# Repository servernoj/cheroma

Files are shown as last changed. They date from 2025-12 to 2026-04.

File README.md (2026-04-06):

# CheRoMa -- Chess Robotic Manipulator

This project represents work files to build and program a 4-DOF robotic manipulator intended to move chess pieces on the board by following live game broadcasted from chess.com (and lichess.org in near future) platforms. The arm is built from budgetary parts (servos, electromagnet, brackets) readily available for purchase from Amazon and other retailers. It also has a number of custom made 3D printed parts with CAD designs included in this repo.

As of April'26 this is a "work in progress" with completion rate of roughly 70-80%. The biggest challenge so far is the lack of precision of budgetary servos that negatively affects positioning of the arm in 3D space (error ±10mm) , which in turn results in inability for the arm to move specific chess piece from/to target position. This problem is being addressed by introducing a Digitizer -- platform allowing to calibrate robot's model params in real time by forcing it to move to specific positions and automatically reading 3D coordinates of the arrival point and using this data to fit model coefficients. 

## Demos

- Cheroma arm moving chess pieces https://www.youtube.com/shorts/CEkricqCiFo
- Cheroma Digitizer prototype is used for arm calibration https://www.youtube.com/shorts/9hFcoPiPavI

# Install the service

## Install NVM + Node + PNPM

Follow steps from https://github.com/nvm-sh/nvm?tab=readme-ov-file#installing-and-updating to install NVM

Then install `Node 22` and `pnpm`
```sh
nvm install 22
nvm alias default 22
npm i -g npm
```

## Install GitHub actions runner

Follow steps in `https://github.com/<username>/<repo>/settings/actions/runners/new`

## Install systemd service

Create file `/etc/systemd/system/cheroma.service` with the following content

```` ini
[Unit]
Description=CheRoMa API Service
After=network.target

[Service]
Type=simple
User=<username>
WorkingDirectory=/home/<username>/cheroma/apps/api
ExecStart=/bin/bash -lc 'source $HOME/.nvm/nvm.sh && node --env-file .env src/index.js'
Restart=on-failure
RestartSec=5
Environment=NODE_ENV=production
TimeoutStopSec=30s
KillSignal=SIGTERM
SendSIGKILL=yes

[Install]
WantedBy=multi-user.target
````
**Note**: replace `<username>` with your actual username on RasPi

Initialize the unit
```` sh
sudo systemctl daemon-reload
sudo systemctl start cheroma.service
````

Use the following to monitor the logs at realtime
```` sh
journalctl -u cheroma -f
```` 

# Misc
```sh
i2cset -y 1 0x40 0x00 0x10 # sleep
i2cset -y 1 0x40 0xFE 0x79 # frequency 50Hz
i2cset -y 1 0x40 0x00 0x20 # wake up + set auto-inc
i2cset -y 1 0x40 0x01 0x0C # set output + configure PWM reload logic

i2cset -y 1 0x40 0x06 0x00 0x00 0x40 0x01 i # center
```

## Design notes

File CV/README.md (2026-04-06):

# Vision server (Python + OpenCV + Flask)

REST API for camera capture and board / motion processing. Intended to run on a Raspberry Pi in production; development can use a Mac or Linux machine with a USB webcam.

## Requirements

- Python 3.10+ recommended (3.14+ tested)
- USB camera (or compatible capture device) when exercising the pipeline

## Setup on a new machine

From the repository root:

```bash
cd CV
python3 -m venv .venv
```

Activate the virtual environment:

- **macOS / Linux:** `source .venv/bin/activate`
- **Windows (cmd):** `.venv\Scripts\activate.bat`
- **Windows (PowerShell):** `.venv\Scripts\Activate.ps1`

Install dependencies:

```bash
pip install --upgrade pip
pip install -r requirements.txt
```

## Run the server

With the venv activated:

```bash
python app.py
```

By default the app listens on **127.0.0.1** port **5050**. Override with environment variables:

| Variable | Default | Description |
|---|---|---|
| `VISION_HOST`  | `127.0.0.1` | Bind address |
| `VISION_PORT`  | `5050` | Port |
| `FLASK_DEBUG`  | `1` | Set to `0` to disable Flask debug mode |
| `VISION_CAMERA_INDEX` | `0` | OpenCV camera index (see Webcam section) |
| `VISION_BOARD_DEBUG_DIR` | *(empty)* | If set: `find_board_corners` writes `overlay.png` there; overlay fit also writes per-candidate GIFs plus `overlay_fit_*_API_WINNER.gif`. Requires `imageio`. |
| `VISION_BOARD_CALIBRATION_FILE` | `CV/board_calibration.json` | Single global board quad (full-frame corners + frame size). |

Example:

```bash
VISION_HOST=0.0.0.0 VISION_PORT=5050 FLASK_DEBUG=0 python app.py
```

## Webcam on macOS (and Linux)

OpenCV does not use a device path like `/dev/video0` in your code on macOS. It opens cameras by **integer index**. Order is **not fixed** (built-in vs USB can swap). The backend on macOS is typically **AVFoundation**.

**macOS:** After unplugging a USB camera, the built-in camera may stay at **index 1** while **index 0** is empty. Probing **index 0** can then take **several seconds** before failing.

Use a working index when running your app or scripts:

```bash
export VISION_CAMERA_INDEX=1
```

**macOS privacy:** The process that runs Python needs camera permission (Terminal, iTerm2, **Cursor**, or **VS Code** if you run from the integrated terminal). Open **System Settings → Privacy & Security → Camera** and enable the app you use. If OpenCV prints “camera access has been denied,” grant access or run from a terminal app that is allowed.

**Programmatic access** in code:

```python
from vision import WebcamCapture

with WebcamCapture() as cam:  # uses VISION_CAMERA_INDEX, default 0
    ok, frame = cam.read()
```

## Check health

```bash
curl -s http://127.0.0.1:5050/health
```

Expected JSON: `{"status":"ok"}`

## Camera HTTP API (dev / test)

- **`GET /api/cameras`** — Runs `probe_cameras()`: one OpenCV index per device from `enumerate_cameras()`, keeping index and name aligned. JSON **`cameras`**: those that open and return a frame. If devices change while the process is running, restart the app so enumeration refreshes.

- **`GET /api/cameras/<index>`** — One **JPEG** frame from that index. Query: **`warmup`** (default `0`), **`quality`** (default `85`). Reopens the camera each request.

- **`GET /api/cameras/<index>/board`** — Warped **JPEG** using **saved calibration** only (no live edge detection). Query: **`warmup`**, **`quality`**, **`size`**. Returns **422** if calibration is missing or frame size does not match (recalibrate after resolution change).

- **`GET /api/cameras/<index>/board/overlay`** — Same warp and calibration gates as **`/board`**, then **first-pass** fit: symmetric scale from full-frame `cell = size/8` down to **`min_scale`×(size/8)`**. The winning scale maximizes **Pearson correlation** between **64 per-cell mean luminances** and a ±1 checker. **`n_steps`** (default **48**, clamped 8–256) is how many **`cell`** samples are placed on that range (inclusive endpoints). Headers **`X-Board-Overlay-Grid-Steps`**, **`X-Board-Overlay-Evaluated-Steps`**, **`X-Board-Overlay-Cell-Range`** report configured vs actually scored steps and `cell` endpoints. Default **`min_scale=0.75`** sweeps a **25%** shrink in `cell`; for a ~**5%** rim try **`min_scale`** closer to **1** (e.g. **`0.95`**). Query **`force_step`** (1-based index into the sweep) draws that step’s grid instead of the best score (preview). Query **`min_ncc`** only sets **`X-Board-Overlay-Meets-Min-Ncc`**. Also: **`warmup`**, **`quality`**, **`size`**, **`overlay_alpha`**.

- **`GET /api/cameras/<index>/board/calibration`** — Same JSON as a successful **POST** and the on-disk file: `ok`, and when calibrated `frame_width`, `frame_height`, `corners` (4×2). Returns `{"ok": false}` when none or invalid file. No capture. Calibration is global; the path index is not persisted.

- **`POST /api/cameras/<index>/board/calibration`** — Capture one frame from that index, run edge detection, **replace** stored calibration with one quad. OpenCV index is only used to open the device; it is not persisted. Returns **422** if no quad found.

- **`DELETE /api/cameras/<index>/board/calibration`** — Clear saved calibration (same global state for any index).

- **`GET /api/cameras/<index>/board-aruco`** — Dev endpoint (ArUco path); returns a JPEG (see `board_aruco`).

Examples:

```bash
curl -s http://127.0.0.1:5050/api/cameras | python3 -m json.tool
curl -s -o /tmp/cam0.jpg "http://127.0.0.1:5050/api/cameras/0"
curl -s http://127.0.0.1:5050/api/cameras/0/board/calibration | python3 -m json.tool
curl -s -X POST "http://127.0.0.1:5050/api/cameras/0/board/calibration"
curl -s -o /tmp/board.jpg "http://127.0.0.1:5050/api/cameras/0/board?size=800"
curl -s -o /tmp/board_overlay.jpg "http://127.0.0.1:5050/api/cameras/0/board/overlay?size=800"
curl -s -o /tmp/board_overlay_s10.jpg "http://127.0.0.1:5050/api/cameras/0/board/overlay?size=800&force_step=10"
```

## API stubs (to be implemented)

- `POST /api/reset` — reseed baseline / flags before a game
- `POST /api/listening/start` — begin the window where moves are expected
- `POST /api/listening/stop` — end that window

The virtual environment directory `.venv/` is gitignored; create it on each machine using the steps above.

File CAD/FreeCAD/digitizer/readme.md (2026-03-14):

The original design (file `base.FCStd`) of the digitizer case has an error related to how the origin of the digitizer pad, i.e. point in the middle of square outlined by pins 45,46,47,48 of the J2_01 connector, will positioned relative to the bottom-left mounting hole. By design their XY coordinates should match, so the digitizer origin should be right above the hole.

But in the implemented part the origin will have offset of 3.74mm towards X- and Y+. In this case when digitizer position will be defined as the `origin` param of the `[POST] /calibration` endpoint, the specified value (assumed to be aligned with the left-bottom mounting hole) will to to be adjusted correspondingly. 

For example, the user submitted `origin: [100, 150, 20]` the actual origin will be `[100 - 3.74, 150 + 3.74, 20]`

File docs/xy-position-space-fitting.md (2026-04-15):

# XY Position-Space Fitting — Design Context

## Hardware Overview

- **4-DOF robotic arm**: 1 yaw (base) + 3 pitch (shoulder, elbow, wrist)
- Hobby servos + 3D printed parts → imprecise positioning
- Wrist enforces tool-pitch constraint: `q3 = gamma - q1 - q2` (gamma=180°), keeping TCP vertical
- **TCP equipment**: electromagnet for grabbing chess pieces; stylus for digitizer calibration
- **Target application**: move chess pieces on a 320×320mm board (8×8, 40mm cells)

## Digitizer Platform

- 32×32 pin array, 160×160mm active area (= one quarter of the chess board)
- Touch registers (row, col) → converted to XY in robot frame via known origin offset
- Origin is measured in 3D arm coordinates; all touches share the same Z as the origin
- XY from digitizer is reliable; Z is NOT (3–15mm suspension travel before interrupt fires)
- Planned: 4 placements (board quarters) × 2 Z-levels = 8 sessions; currently only 1 origin is practical

## Why the Previous FK-Based Fitting Failed

### Approach
`Xmeas ≈ R(roll,pitch,yaw) · FK(a·Qcmd + b) + t` — fit per-servo scale/offset (a,b) + 6-DOF registration (R,t) using `lsqnonlin`.

### Problems identified

1. **XY-only residuals leave Z unconstrained** — registration angles (roll, pitch) and tz are weakly observable. The solver pushes them to bounds or trades them against servo params.

2. **Parameter ambiguity** — registration yaw vs base servo offset are confounded (both rotate XY). Translation tx,ty trade off with pitch-chain offsets. Different (R,t,a,b) combos produce identical XY predictions but wildly different Z behavior.

3. **Gamma constraint mismatch** — the fitter uses `q3 = gamma - q1_corrected - q2_corrected` (actual-side), but during calibration with identity correction the physical arm had `q3 = gamma - q1_commanded - q2_commanded + wrist_error`. The fitter's a,b absorb wrist error into shoulder/elbow corrections, making them non-physical. Switching to command-side gamma made a,b even less constrained (shoulder b jumped to −23°).

4. **Qcmd encodes a specific Z that the fitter ignores** — `Qcmd = IK(x_target, y_target, z_at_touch)` where z_at_touch varies per sample (interrupt timing). The fitter treats these angles as arbitrary, establishing no link between the commanded Z and the measured XY. Different Z → different Qcmd → same measured XY → the fitter cannot uniquely decompose the error.

## New Approach: Position-Space Fitting

Instead of decomposing error into per-joint corrections via FK, model the **XY positioning error as a function of target position** directly.

### Data model
For each calibration sample:
- **Target**: `(x_t, y_t)` — where we commanded the arm to go (known from grid geometry + origin)
- **Measured**: `(x_m, y_m)` — where the arm actually touched (from digitizer)
- **Error**: `(dx, dy) = (x_m - x_t, y_m - y_t)`

### Fitting
Model the error field:
```
dx(x, y) = a0 + a1·x + a2·y       (affine: 6 params)
dy(x, y) = b0 + b1·x + b2·y

dx(x, y) = a0 + a1·x + a2·y + a3·x² + a4·xy + a5·y²   (quadratic: 12 params)
dy(x, y) = b0 + b1·x + b2·y + b3·x² + b4·xy + b5·y²
```

Well-determined: 64 samples × 2 residuals vs 6–12 params. No FK, no registration, no ambiguity.

### Deployment
To reach desired `(x_d, y_d, z)`:
```
IK(x_d - dx(x_d, y_d),  y_d - dy(x_d, y_d),  z)
```
Pre-distort the target XY before feeding into IK. No servo correction layer needed.

### Z generalization
- Calibrate at two digitizer heights → two sets of affine/quadratic coefficients
- Interpolate coefficients for intermediate Z (chess piece heights range 35–75mm)

## Current State of the Codebase

**Branch**: `xy-position-space-fitting` (branched from `dev`)
**Restore tag**: `pre-xy-position-space-fitting` on `dev`

### What was removed
- `config.json`: top-level `fitting` (roll,pitch,yaw,t) + per-servo `fitting` (scale,offset)
- `@types/global.d.ts`: `Fitting` type, `ServoFitting` type, `fitting` fields on `ServoData` and `Config`
- `modules/kinematics.js`: `toModel()` function, `fitting` variable, `Matrix`/`rotationMatrix` imports; `IKK` simplified to `K2S(IK(P))`
- `modules/servo.js`: `angleDegToPulseUs` no longer applies scale/offset — angle goes straight to calPoints; `line()` uses `IKK` instead of `K2S(IK(toModel(...)))`
- `controller/config.js`: `fittingSchema`, `servoFittingSchema`, `fitting` from PATCH schema
- `modules/xyzFitting.js`: deleted (old JS Levenberg-Marquardt fitter)
- `fit-calibration.js`: deleted (CLI entry point for old fitter)
- `package.json`: removed `fit-calibration` script

### What remains unchanged
- `modules/calibration.js` — calibration experiment workflow (descent, touch, record)
- `controller/calibration.js` — POST endpoint returning CSV
- `modules/arm.js`, `controller/arm.js` — arm motion (use IKK, which now passes through directly)
- `matlab/xy_fitting.m` — Matlab XY fitter (kept for reference, not used going forward)
- `matlab/xyz_fitting.m` — Matlab XYZ fitter (kept for reference)

## TODO — Next Steps

1. **Update calibration CSV format**: include `x_target, y_target` (known from grid) alongside `x_measured, y_measured` (from digitizer). Qcmd columns may become optional or removed.

2. **Implement position-space fitter** (JS module): least-squares fit of affine or polynomial error model from (target, measured) pairs.

3. **Add XY correction to config**: new config section for the polynomial coefficients (replaces old fitting block).

4. **Integrate correction into IKK** (or a new wrapper): apply pre-distortion before IK.

5. **Collect fresh calibration data** with identity correction (current state) and validate the new approach.

6. **Multi-Z support**: repeat calibration at elevated digitizer, fit per-Z, implement interpolation.

## Key Files for Context

| File | Role |
|---|---|
| `apps/api/src/modules/kinematics.js` | FK, IK, IKK (now raw) |
| `apps/api/src/modules/servo.js` | Angle→pulse, motion planning, `line()` |
| `apps/api/src/modules/calibration.js` | Calibration experiment: grid traversal, descent, digitizer read |
| `apps/api/src/controller/calibration.js` | HTTP endpoint for calibration |
| `apps/api/src/modules/arm.js` | High-level arm motions (descent, lift, search) |
| `apps/api/src/config.json` | Runtime config (geom, servos, board) |
| `apps/api/src/@types/global.d.ts` | TypeScript type definitions |
| `apps/api/take_1.csv` | Sample calibration data (64 rows, 7 cols) |

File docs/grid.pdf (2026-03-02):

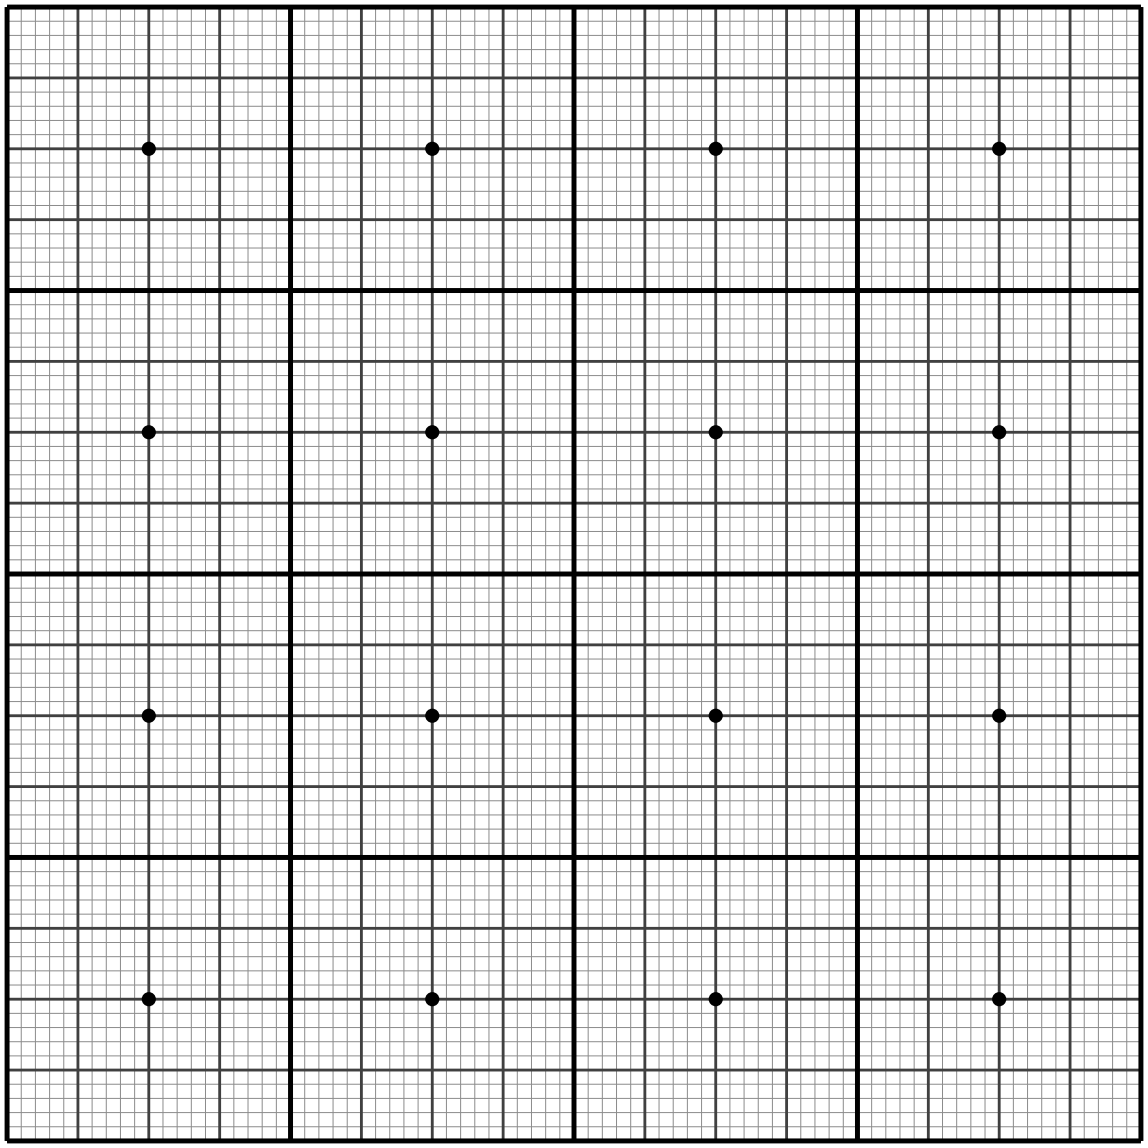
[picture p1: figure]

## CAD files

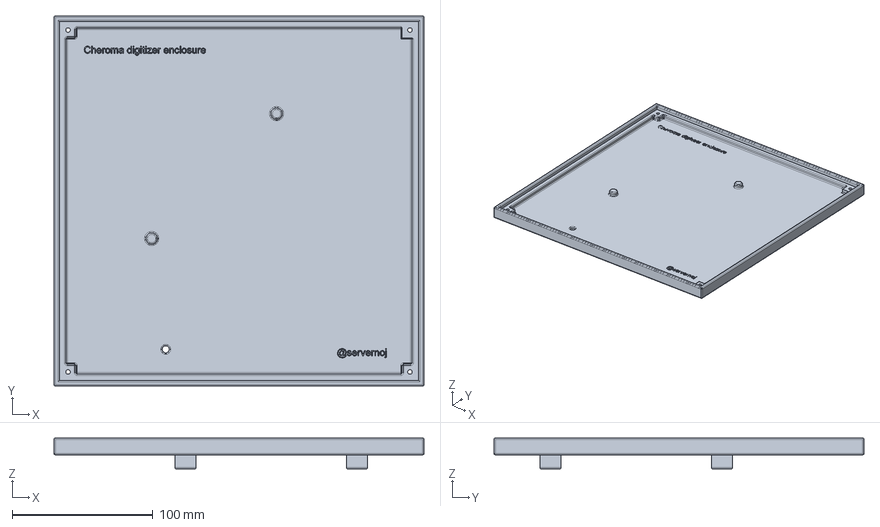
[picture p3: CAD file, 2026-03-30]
CAD/FreeCAD/digitizer/base_rev1.2.FCStd
263.0 x 263.0 x 22.0 mm

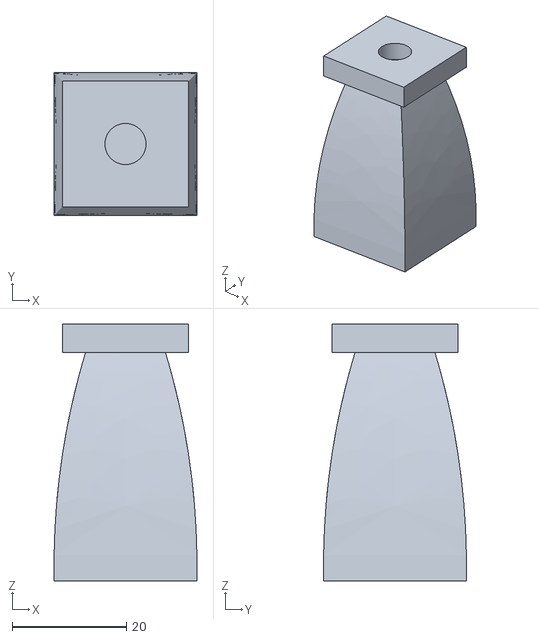
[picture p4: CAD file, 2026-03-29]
CAD/FreeCAD/pieces/hollow/pieces-rook.stl
25.0 x 25.0 x 45.0

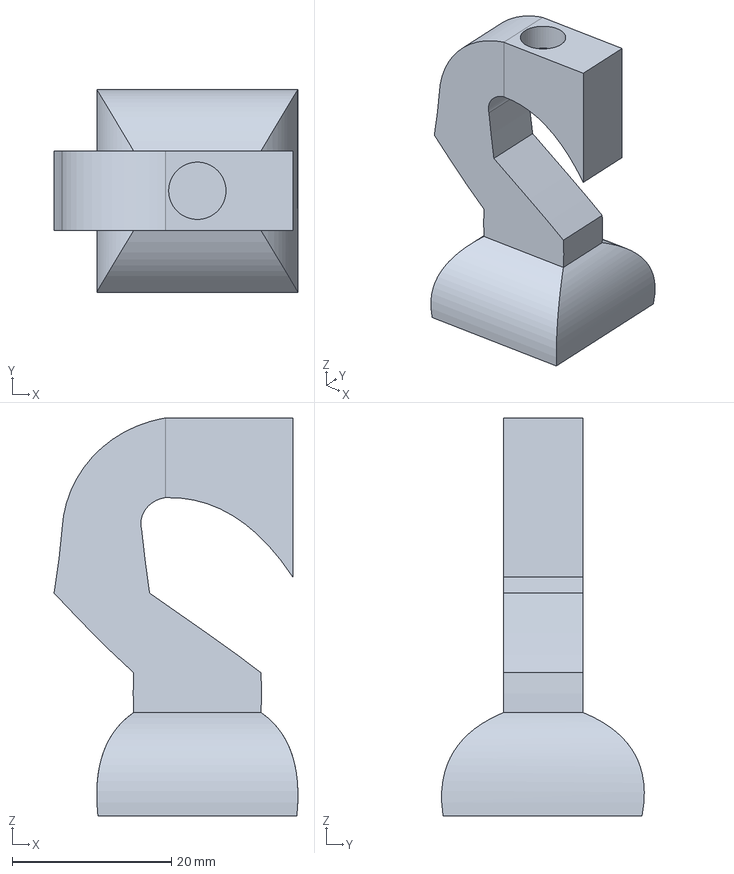
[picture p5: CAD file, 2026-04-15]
CAD/FreeCAD/pieces/pieces.FCStd
30.6 x 25.5 x 50.0 mm

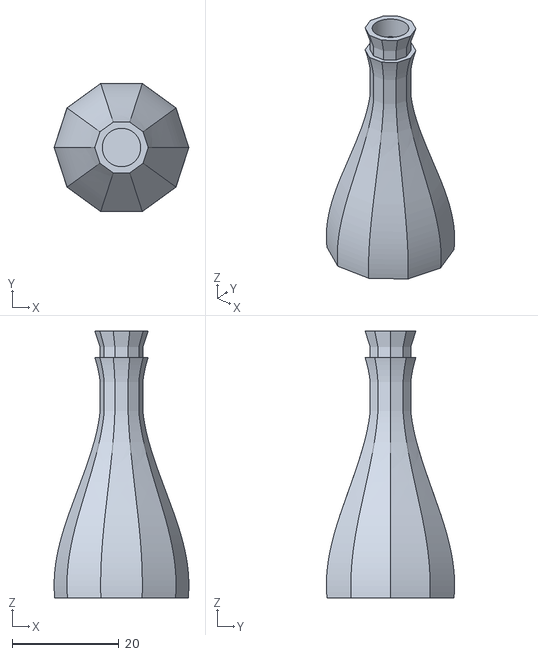
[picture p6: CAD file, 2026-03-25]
CAD/FreeCAD/pieces/solid/pieces-bishop.stl
25.2 x 24.0 x 50.0

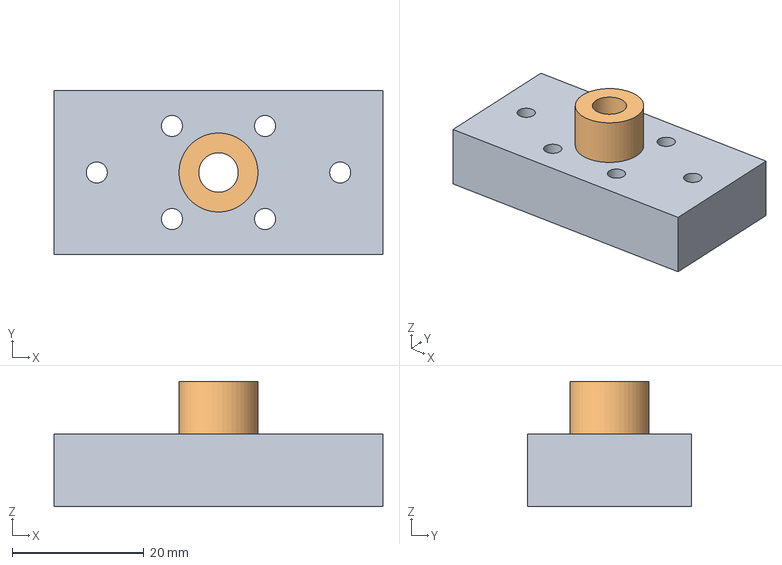
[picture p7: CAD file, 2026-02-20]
CAD/FreeCAD/TCP/tcp_adapter.FCStd
50.0 x 25.0 x 19.0 mm
holder
insert

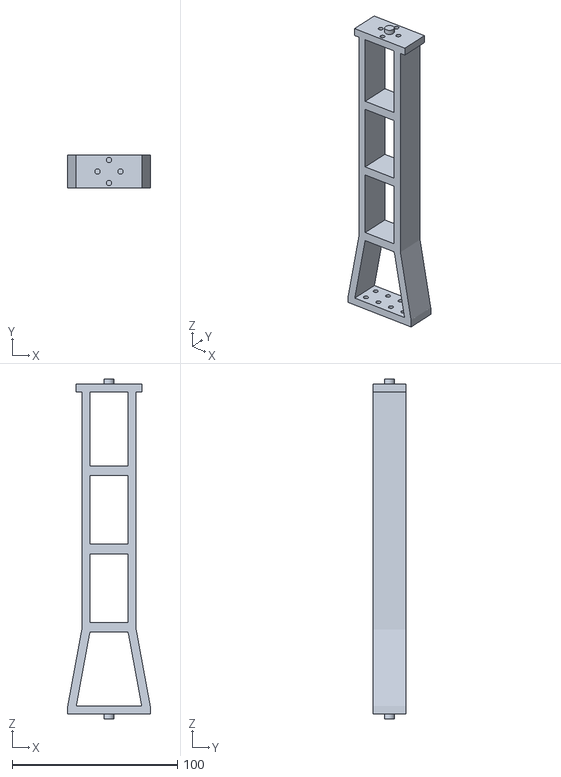
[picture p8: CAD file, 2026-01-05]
CAD/OpenSCAD/P2.stl
50.0 x 20.0 x 206.0

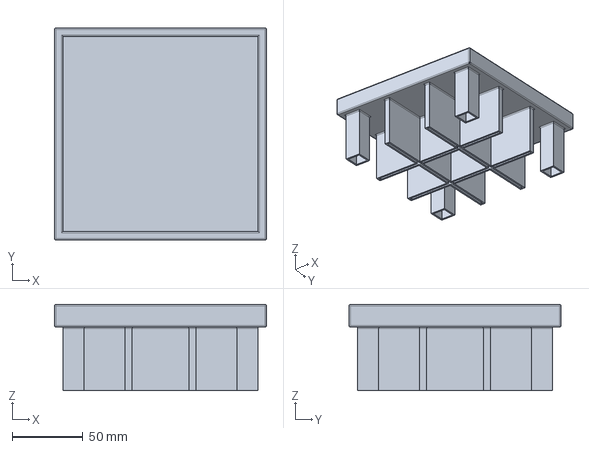
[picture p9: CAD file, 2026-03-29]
CAD/FreeCAD/digitizer/spacer_rev1.1.FCStd
150.0 x 150.0 x 61.0 mm

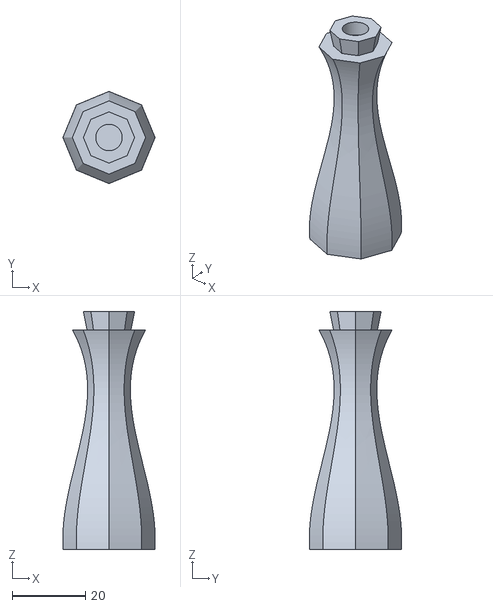
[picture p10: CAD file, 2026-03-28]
CAD/FreeCAD/pieces/hollow/pieces-queen.stl
25.2 x 25.2 x 65.0

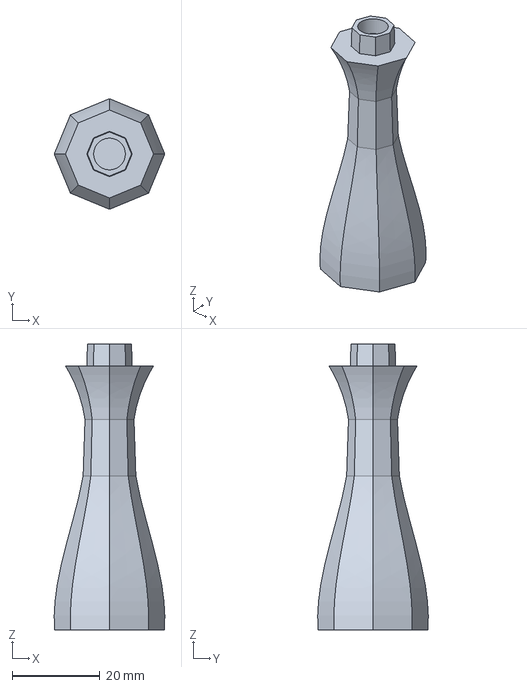
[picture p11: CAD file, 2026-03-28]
CAD/FreeCAD/pieces/pieces-solid.FCStd
25.1 x 25.1 x 65.0 mm

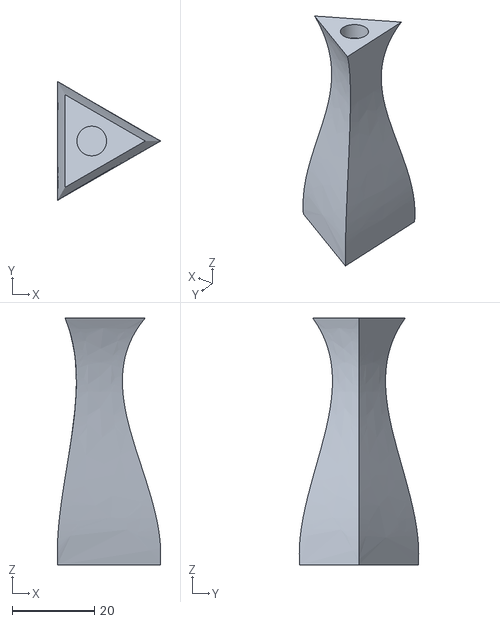
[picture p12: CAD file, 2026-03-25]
CAD/FreeCAD/pieces/solid/pieces-king.stl
25.1 x 29.0 x 60.0

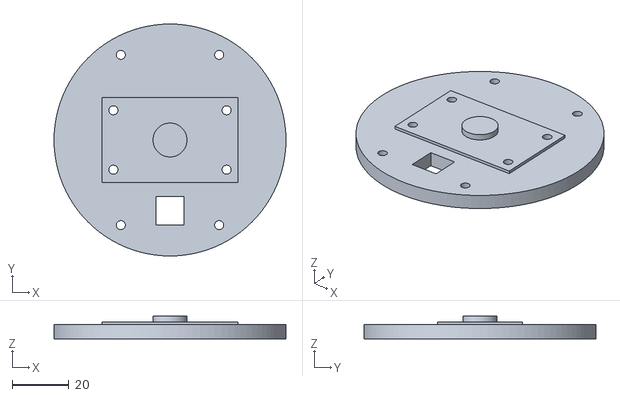
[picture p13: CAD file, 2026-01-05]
CAD/OpenSCAD/base_rds_5180.stl
82.0 x 82.0 x 8.00

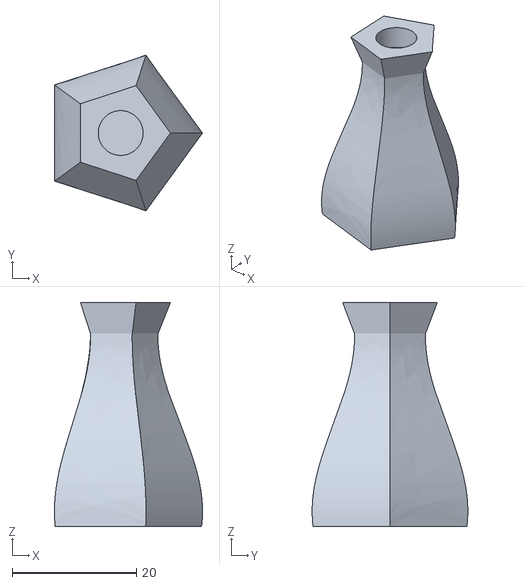
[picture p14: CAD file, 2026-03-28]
CAD/FreeCAD/pieces/hollow/pieces-pawn.stl
23.8 x 25.0 x 36.0

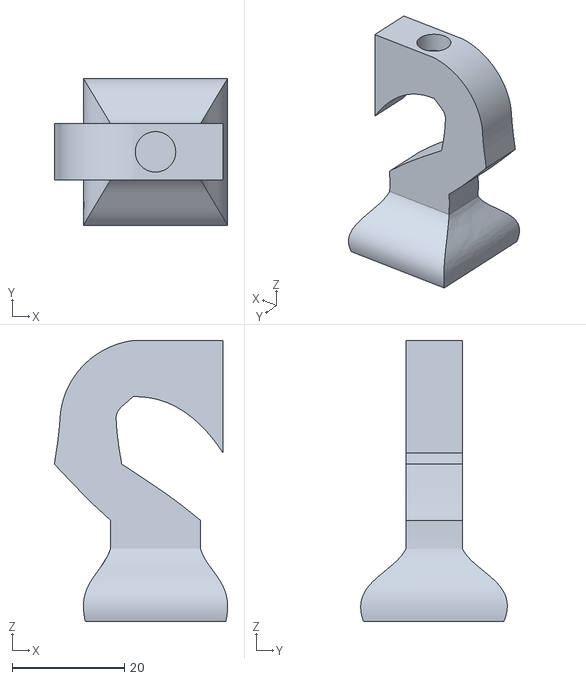
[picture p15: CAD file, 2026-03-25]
CAD/FreeCAD/pieces/solid/pieces-knight.stl
30.8 x 26.1 x 50.0

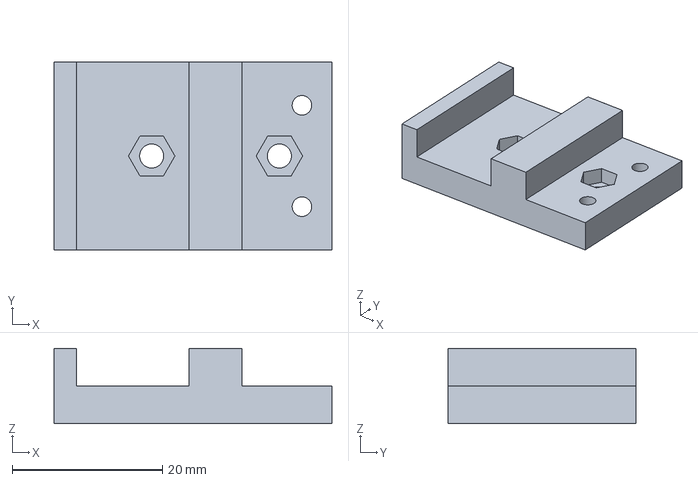
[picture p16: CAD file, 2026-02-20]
CAD/FreeCAD/TCP/pcb_holder.FCStd
37.0 x 25.0 x 10.0 mm

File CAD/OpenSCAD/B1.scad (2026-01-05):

// B1 bracket interface (visual approval model)
//
// Geometry described by user:
// - Outer interface rectangle: 56mm x 21mm
// - Center hole: Ø9mm at (0,0)
// - M3 holes:
//   - 8 holes at corners AND edge-centers of an inscribed aligned rectangle 42mm x 14mm
//     (i.e. corners ±21,±7 plus edge centers ±21,0 and 0,±7)
//   - 2 additional M3 holes on the long symmetry axis (X axis) at x=±7mm

// ----------------------------
// Parameters
// ----------------------------
plate_x = 56;            // mm (long dimension)
plate_y = 21;            // mm (short dimension)
plate_thickness = 3;     // mm (visualization thickness)

center_hole_d = 9;       // mm
m3_hole_d = 3.2;         // mm (clearance)

// Inscribed rectangle for the 8-hole pattern
inscribed_x = 42;        // mm (along X)
inscribed_y = 14;        // mm (along Y)

$fn = 96;

// ----------------------------
// Helpers
// ----------------------------
module hole(d, h) {
    cylinder(d=d, h=h, center=true);
}

module plate() {
    linear_extrude(height=plate_thickness)
        square([plate_x, plate_y], center=true);
}

module b1_holes() {
    h = plate_thickness + 2;

    // Center Ø9 hole
    translate([0, 0, plate_thickness/2])
        hole(center_hole_d, h);

    // 8 M3 holes: corners + edge-centers of inscribed rectangle
    ix = inscribed_x/2;
    iy = inscribed_y/2;

    // corners
    for (sx = [-1, 1], sy = [-1, 1])
        translate([sx*ix, sy*iy, plate_thickness/2])
            hole(m3_hole_d, h);

    // edge centers
    for (sx = [-1, 1])
        translate([sx*ix, 0, plate_thickness/2])
            hole(m3_hole_d, h);

    for (sy = [-1, 1])
        translate([0, sy*iy, plate_thickness/2])
            hole(m3_hole_d, h);

    // 2 additional M3 holes on long symmetry axis at x=±7
    for (sx = [-1, 1])
        translate([sx*7, 0, plate_thickness/2])
            hole(m3_hole_d, h);
}

// ----------------------------
// Model
// ----------------------------
difference() {
    plate();
    b1_holes();
}

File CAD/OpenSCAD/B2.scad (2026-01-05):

// B2 bracket interface (visual approval model)
//
// Geometry described by user:
// - Outer interface rectangle: 40mm x 20mm
// - Center hole: Ø6mm at (0,0)
// - 4x M3 holes on lines of symmetry, spaced 7mm from center:
//   (±7, 0) and (0, ±7)
//
// Coordinate system:
// - Origin at plate center
// - X = long axis (40mm)
// - Y = short axis (20mm)

// ----------------------------
// Parameters
// ----------------------------
plate_x = 40;            // mm
plate_y = 20;            // mm
plate_thickness = 3;     // mm (visualization thickness)

center_hole_d = 6;       // mm
m3_hole_d = 3.2;         // mm (clearance)

hole_offset = 7;         // mm from center along symmetry axes

$fn = 96;

module hole(d, h) {
    cylinder(d=d, h=h, center=true);
}

module plate() {
    linear_extrude(height=plate_thickness)
        square([plate_x, plate_y], center=true);
}

difference() {
    plate();

    h = plate_thickness + 2;

    // Center hole
    translate([0, 0, plate_thickness/2])
        hole(center_hole_d, h);

    // 4x M3 holes at (±7,0), (0,±7)
    for (sx = [-1, 1])
        translate([sx*hole_offset, 0, plate_thickness/2])
            hole(m3_hole_d, h);

    for (sy = [-1, 1])
        translate([0, sy*hole_offset, plate_thickness/2])
            hole(m3_hole_d, h);
}

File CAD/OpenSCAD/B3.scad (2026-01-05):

// B3 bracket interface (visual approval model)
//
// Geometry described by user:
// - Outer interface rectangle: 50mm x 20mm
// - Center hole: Ø6mm at (0,0)
// - 8x M3 holes located at the corners of THREE squares placed side-by-side
//   along the long symmetry axis (X axis), with the middle square centered at origin.
//
// Interpretation (yields 8 holes as stated):
// - The 3 squares share edges (forming a 1x3 strip), so their corner set is a 4x2 grid.
// - Each square has diagonal = 14mm, so side = 14/sqrt(2).
// - Hole coordinates are at x = (-1.5a, -0.5a, +0.5a, +1.5a) and y = (±a/2), where a=side.
//
// Coordinate system:
// - Origin at plate center
// - X = long axis (50mm)
// - Y = short axis (20mm)

// ----------------------------
// Parameters
// ----------------------------
plate_x = 50;            // mm
plate_y = 20;            // mm
plate_thickness = 3;     // mm (visualization thickness)

center_hole_d = 6;       // mm
m3_hole_d = 3.2;         // mm (clearance)

square_diag = 14;        // mm (diagonal of each square)

$fn = 96;

module hole(d, h) {
    cylinder(d=d, h=h, center=true);
}

module plate() {
    linear_extrude(height=plate_thickness)
        square([plate_x, plate_y], center=true);
}

// ----------------------------
// Model
// ----------------------------
difference() {
    plate();

    h = plate_thickness + 2;

    // Center hole
    translate([0, 0, plate_thickness/2])
        hole(center_hole_d, h);

    // 8x M3 holes from 3 edge-sharing squares
    a = square_diag / sqrt(2); // side length

    xs = [-1.5*a, -0.5*a, 0.5*a, 1.5*a];
    ys = [-0.5*a, 0.5*a];

    for (x = xs, y = ys)
        translate([x, y, plate_thickness/2])
            hole(m3_hole_d, h);
}

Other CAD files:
CAD/FreeCAD/TCP/tcp_assembly.FCStd
CAD/OpenSCAD/P1.stl
CAD/FreeCAD/pieces/hollow/pieces-bishop.stl
CAD/FreeCAD/pieces/solid/pieces-pawn.stl
CAD/OpenSCAD/base.scad
CAD/FreeCAD/TCP/pcb_holder.stl
CAD/FreeCAD/TCP/tcp_adapter.stl
CAD/FreeCAD/digitizer/base_rev1.2.stl
CAD/FreeCAD/digitizer/spacer.FCStd
CAD/FreeCAD/digitizer/spacer_rev1.1.stl
CAD/FreeCAD/pieces/hollow/pieces-king.stl
CAD/FreeCAD/pieces/hollow/pieces-knight.stl
CAD/FreeCAD/pieces/solid/pieces-queen.stl
CAD/FreeCAD/pieces/solid/pieces-rook.stl
CAD/OpenSCAD/P1.scad
CAD/OpenSCAD/P2.scad
CAD/OpenSCAD/P3.scad
CAD/OpenSCAD/P3.stl

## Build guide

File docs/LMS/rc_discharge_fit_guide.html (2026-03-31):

# RC discharge: identify \(V_0\) and \(\tau\) from \((t, V)\) data

Step-by-step guide for MATLAB. You enter ts and vs and run the steps yourself. Math below uses LaTeX (MathJax). No noise is assumed in your synthetic experiment.

## Model and residual

Time constant \(\tau = RC\). Ideal capacitor discharge:

$$V(t) = V_0\, e^{-t/\tau}$$

Parameter vector (column \(2 \times 1\)):

$$\mathbf{p} = \begin{pmatrix} V_0 \\ \tau \end{pmatrix}$$

For each sample \(k = 1,\ldots,N\), with measurements \((t_k, V^{\mathrm{meas}}_k)\) stored as ts(k), vs(k):

$$r_k(\mathbf{p}) = V^{\mathrm{meas}}_k - V_0\, e^{-t_k/\tau}$$

Stack \(\mathbf{r}(\mathbf{p}) = [r_1,\ldots,r_N]^\top\). Objective (half sum of squares):

$$\Phi(\mathbf{p}) = \tfrac{1}{2}\,\|\mathbf{r}\|_2^2 = \tfrac{1}{2}\sum_{k=1}^N r_k^2$$

## Stage 0 — Data in MATLAB and a plot

You do:

1. Define column vectors ts and vs.
2. plot(ts, vs, 'o'); label axes.
3. Check numel(ts) == numel(vs).

Why: If \(t=0\) is the start of discharge, \(V_0\) is the model value at \(t=0\) (possibly extrapolated if your first sample has \(t_1 > 0\)).

## Stage 1 — Residual function \(\mathbf{r}(\mathbf{p})\)

You do: Implement r = residual_rc(p, ts, vs) with p(1)=V_0, p(2)=tau:

function r = residual_rc(p, ts, vs)
  V0 = p(1);
  tau = p(2);
  vhat = V0 * exp(-ts / tau);
  r = vs - vhat;
end

Pick a trial \(\mathbf{p}_0 = [V_{0,\mathrm{guess}};\,\tau_{\mathrm{guess}}]^\top\). Compute r0 = residual_rc(p0, ts, vs) and

$$\Phi(\mathbf{p}_0) = \tfrac{1}{2}\,\mathbf{r}_0^\top \mathbf{r}_0$$

## Stage 2a — Numerical Jacobian \(\mathbf{J}\)

Dimensions: \(\mathbf{J} \in \mathbb{R}^{N \times 2}\), with \(J_{kj} = \partial r_k / \partial p_j\).

Meaning of \(\mathbf{e}_1\), \(\mathbf{e}_2\), \(h_1\), \(h_2\).

\(\mathbf{e}_1\) and \(\mathbf{e}_2\) are the standard basis vectors in \(\mathbb{R}^2\) (you have two parameters):

$$\mathbf{e}_1 = \begin{pmatrix} 1 \\ 0 \end{pmatrix}, \qquad \mathbf{e}_2 = \begin{pmatrix} 0 \\ 1 \end{pmatrix}$$

So \(\mathbf{p} + h_1 \mathbf{e}_1\) bumps only \(V_0\) by \(h_1\), and \(\mathbf{p} + h_2 \mathbf{e}_2\) bumps only \(\tau\) by \(h_2\). Each column of \(\mathbf{J}\) is the rate of change of \(\mathbf{r}\) along one coordinate of \(\mathbf{p}\).

\(h_1\) and \(h_2\) are small finite-difference step sizes for those two coordinates. They may differ because \(V_0\) and \(\tau\) can live on very different scales (e.g. volts vs seconds). A common rule is something like \(h_j \sim 10^{-6}\max(1, |p_j|)\), not necessarily one shared \(h\) for both.

In each case you approximate a partial derivative:

$$\frac{\partial \mathbf{r}}{\partial p_j} \approx \frac{\mathbf{r}(\mathbf{p} + h_j \mathbf{e}_j) - \mathbf{r}(\mathbf{p})}{h_j}$$

Forward differences (you choose small \(h_1, h_2\)):

$$\mathbf{J}_{:1} \approx \frac{\mathbf{r}(\mathbf{p} + h_1 \mathbf{e}_1) - \mathbf{r}(\mathbf{p})}{h_1}, \qquad \mathbf{J}_{:2} \approx \frac{\mathbf{r}(\mathbf{p} + h_2 \mathbf{e}_2) - \mathbf{r}(\mathbf{p})}{h_2}$$

with \(\mathbf{e}_1 = [1,0]^\top\), \(\mathbf{e}_2 = [0,1]^\top\). In MATLAB: e1 = [1;0]; e2 = [0;1]; then build J(:,1), J(:,2); confirm size(J) == [N,2].

## Stage 3 — Gauss–Newton step

Normal equations for the Gauss–Newton increment \(\Delta\mathbf{p}\):

$$\mathbf{J}^\top \mathbf{J}\,\Delta\mathbf{p} = -\mathbf{J}^\top \mathbf{r}$$

Then \(\mathbf{p}_{\mathrm{new}} = \mathbf{p} + \Delta\mathbf{p}\).

A = J' * J;
b = -(J' * r0);
dp = A \ b;
p1 = p0 + dp;

Recompute \(\mathbf{r}\) at \(\mathbf{p}_1\); compare \(\Phi\) before and after. Loop until \(\|\Delta\mathbf{p}\|\) is small.

## Stage 2b — Analytical Jacobian

Predicted voltage \(\hat{V}(t) = V_0 e^{-t/\tau}\). Since \(r_k = V^{\mathrm{meas}}_k - \hat{V}(t_k)\),

$$\frac{\partial r_k}{\partial V_0} = -\frac{\partial \hat{V}}{\partial V_0}, \qquad \frac{\partial r_k}{\partial \tau} = -\frac{\partial \hat{V}}{\partial \tau}$$

Derivatives of \(\hat{V}(t) = V_0 e^{-t/\tau}\):

$$\frac{\partial \hat{V}}{\partial V_0} = e^{-t/\tau}$$

Using \(\dfrac{d}{d\tau} e^{-t/\tau} = e^{-t/\tau}\cdot \dfrac{t}{\tau^2}\):

$$\frac{\partial \hat{V}}{\partial \tau} = V_0\, e^{-t/\tau}\,\frac{t}{\tau^2}$$

So (column-wise, evaluated at each ts(k)):

$$\mathbf{J}_{:1} = -\exp(-\mathbf{t}/\tau), \qquad \mathbf{J}_{:2} = -V_0\, \exp(-\mathbf{t}/\tau) \odot (\mathbf{t}/\tau^2)$$

where \(\mathbf{t}\) is the vector ts and \(\odot\) is element-wise product (use .* in MATLAB).

You do: J = jacobian_rc_analytic(p, ts) returning N×2; repeat Stage 3.

## Stage 4 — Optional: Levenberg–Marquardt

What is \(\Phi\)? The scalar objective you minimize is the half sum of squared residuals (same \(\Phi\) as in the model section):

$$\Phi(\mathbf{p}) = \tfrac{1}{2}\,\|\mathbf{r}(\mathbf{p})\|_2^2 = \tfrac{1}{2}\sum_k r_k^2.$$

So “\(\Phi\) decreased” means the total squared error decreased. Each GN/LM step tries to choose \(\Delta\mathbf{p}\) so that \(\Phi(\mathbf{p}+\Delta\mathbf{p})\) is smaller than \(\Phi(\mathbf{p})\), using a linear approximation of \(\mathbf{r}\) near \(\mathbf{p}\).

What is \(\lambda\)? A non‑negative damping parameter (Levenberg–Marquardt). It does not come from the RC physics; it is only a numerical knob for the solver. Roughly:

- \(\lambda\) small → the step is close to Gauss–Newton (uses \(\mathbf{J}^\top\mathbf{J}\) aggressively).
- \(\lambda\) large → the step is smaller and behaves more like a short move along the negative gradient of \(\Phi\) (since \(\mathbf{J}^\top\mathbf{r} = \nabla\Phi\)), i.e. more cautious.

In practice: increase \(\lambda\) when a proposed step would increase \(\Phi\) or is unstable; decrease \(\lambda\) when steps are accepted and convergence is healthy.

Why add \(\lambda \mathbf{I}\) to \(\mathbf{J}^\top\mathbf{J}\)? The Gauss–Newton system is \(\mathbf{J}^\top\mathbf{J}\,\Delta\mathbf{p} = -\mathbf{J}^\top\mathbf{r}\). Two common failures:

1. Singular or ill‑conditioned \(\mathbf{J}^\top\mathbf{J}\): the solve for \(\Delta\mathbf{p}\) is badly posed; \(\Delta\mathbf{p}\) can be huge or hypersensitive to tiny errors.
2. Linearization poor far from the minimum: a full GN step can overshoot, so \(\Phi(\mathbf{p}+\Delta\mathbf{p}) > \Phi(\mathbf{p})\).

Replacing \(\mathbf{J}^\top\mathbf{J}\) by \(\mathbf{J}^\top\mathbf{J} + \lambda \mathbf{I}\) gives:

$$(\mathbf{J}^\top \mathbf{J} + \lambda \mathbf{I})\,\Delta\mathbf{p} = -\mathbf{J}^\top \mathbf{r}$$

Effects: (i) With \(\lambda > 0\), the matrix is better conditioned (strictly positive definite in the usual case), so the linear system for \(\Delta\mathbf{p}\) is more stable and wild steps from near‑singularity are curbed. (ii) Increasing \(\lambda\) shrinks \(\Delta\mathbf{p}\), trading GN aggressiveness for robustness when the quadratic model of \(\Phi\) is unreliable.

One‑line intuition: GN trusts the linearization fully; LM adds “\(\lambda \mathbf{I}\)” to damp the step—if the full GN move is bad, blend in a shorter, gradient‑like correction.

You do: Implement the same solve with A = J'*J + lambda*eye(2), tune \(\lambda\) by hand, or mirror the accept/reject schedule used in your JS fitter.

## Stage 5 — MATLAB lsqnonlin (check)

lsqnonlin(@(p) residual_rc(p, ts, vs), p0, ...) and compare to your GN iterations.

## Stage 6 — Optional: log-domain line fit (warm start only)

If \(V_k > 0\) for all \(k\), then \(\ln V_k = \ln V_0 - t_k/\tau\) is affine in \(t_k\). Linear regression on \((t_k, \ln V_k)\) gives rough \((\ln V_0,\, -1/\tau)\) — useful for \(\mathbf{p}_0\), not a replacement for nonlinear least squares when noise or model mismatch matter.

## Appendix — Why \(\Phi\) decreases: gradient and descent direction

This section generalizes beyond the RC example. Read the formulas here with MathJax rendering enabled.

Objective and gradient. With \(\Phi(\mathbf{p}) = \tfrac{1}{2}\,\|\mathbf{r}(\mathbf{p})\|_2^2\), one has (chain rule):

$$\nabla \Phi(\mathbf{p}) = \mathbf{J}(\mathbf{p})^\top \mathbf{r}(\mathbf{p})$$

The gradient is a vector in \(\mathbb{R}^M\). It points in the direction of steepest increase of \(\Phi\). At an unconstrained minimizer, \(\nabla\Phi(\mathbf{p}^\ast)=\mathbf{0}\).

It is not correct to say the gradient is “negative” as a whole: components can have mixed signs, and the direction depends on where \(\mathbf{p}\) lies.

Directional derivative along a step \(\Delta\mathbf{p}\). The rate of change of \(\Phi\) as you move from \(\mathbf{p}\) in direction \(\Delta\mathbf{p}\) is

$$\left.\frac{d}{d\alpha}\Phi(\mathbf{p}+\alpha\Delta\mathbf{p})\right|_{\alpha=0} = \nabla\Phi(\mathbf{p})^\top \Delta\mathbf{p}$$

A descent direction satisfies \(\nabla\Phi(\mathbf{p})^\top \Delta\mathbf{p} < 0\): then for sufficiently small step length, \(\Phi\) decreases. That is the precise meaning of “\(\Phi\) goes down because its rate of change along the update is negative.”

Gauss–Newton chooses \(\Delta\mathbf{p}\) from the linearized model so that (under standard assumptions) this inner product is negative — a descent step. Levenberg–Marquardt shrinks \(\Delta\mathbf{p}\) when needed so that an accepted step still reduces \(\Phi\) (or increases \(\lambda\) until it does).

Linear-in-parameters models (strong case). If \(\mathbf{r}(\mathbf{p}) = \mathbf{A}\mathbf{p}-\mathbf{b}\) (affine in \(\mathbf{p}\)), then \(\Phi(\mathbf{p})\) is a convex quadratic. Gauss–Newton coincides with minimizing that quadratic exactly: one solve reaches the global minimizer (in exact arithmetic). Example: scalar \(y_i \approx k x_i\) gives \(\Phi(k)=\tfrac{1}{2}\sum_i (y_i-kx_i)^2\), a parabola in \(k\).

Nonlinear \(\mathbf{r}\) (typical calibration). Then \(\Phi\) is not a global quadratic. There is no universal guarantee that every raw GN step reduces \(\Phi\); trust-region / LM damping and step acceptance rules are what enforce practical decrease. Convergence is usually local (good initial guess, full-rank Jacobian), not “from any start to a global minimum.”

Also: \(\Phi\to 0\) only if the model can fit all data exactly (\(\mathbf{r}=\mathbf{0}\)); with noise or model error, the minimum \(\Phi\) is typically positive.

Progress log: Record \(\mathbf{p}_0\), first \(\Delta\mathbf{p}\), and converged \(\mathbf{p}\) as you go.

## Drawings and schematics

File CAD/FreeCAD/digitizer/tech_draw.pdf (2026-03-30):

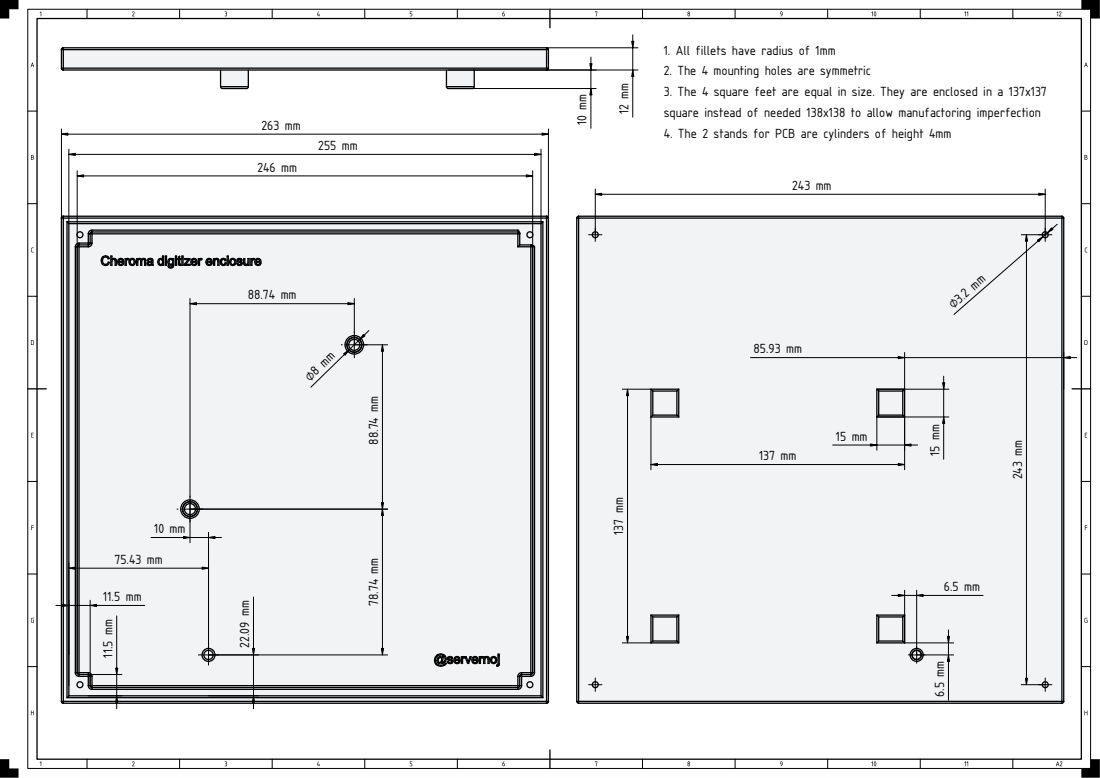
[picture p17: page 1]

1. All fillets have radius of 1mm
2. The 4 mounting holes are symmetric
3. The 4 square feet are equal in size. They are enclosed in a 137x137
square instead of needed 138x138 to allow manufactoring imperfection
4. The 2 stands for PCB are cylinders of height 4mm

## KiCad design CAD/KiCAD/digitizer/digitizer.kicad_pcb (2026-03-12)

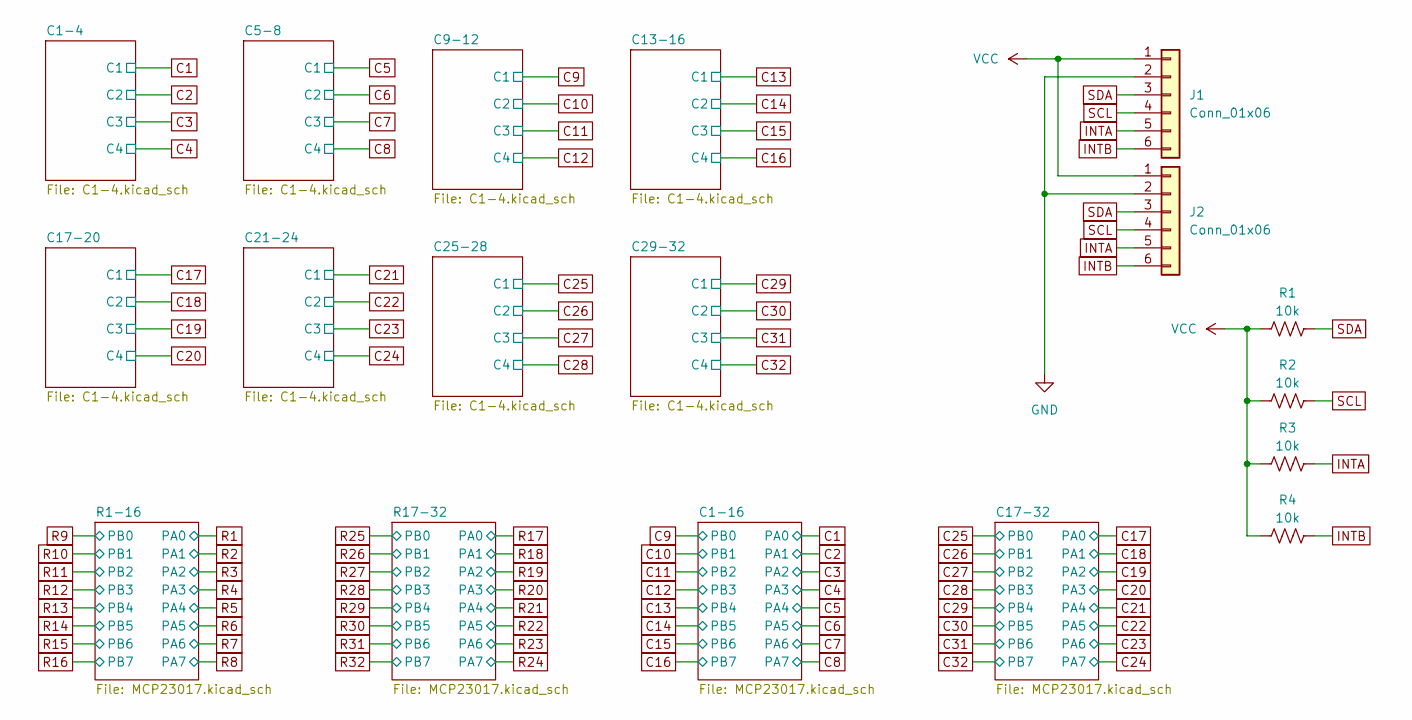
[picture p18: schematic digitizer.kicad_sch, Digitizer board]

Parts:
J1, J2: Conn_01x06; PinHeader_1x06_P2.54mm_Vertical
R1, R2, R3, R4: 10k; R_Axial_DIN0207_L6.3mm_D2.5mm_P15.24mm_Horizontal

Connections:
GND: J1.2, J2.2; also elsewhere on the board
INTA: J1.5, J2.5, R3.2; also elsewhere on the board
INTB: J1.6, J2.6, R4.2; also elsewhere on the board
SCL: J1.4, J2.4, R2.2; also elsewhere on the board
SDA: J1.3, J2.3, R1.2; also elsewhere on the board
VCC: J1.1, J2.1, R1.1, R2.1, R3.1, R4.1; also elsewhere on the board

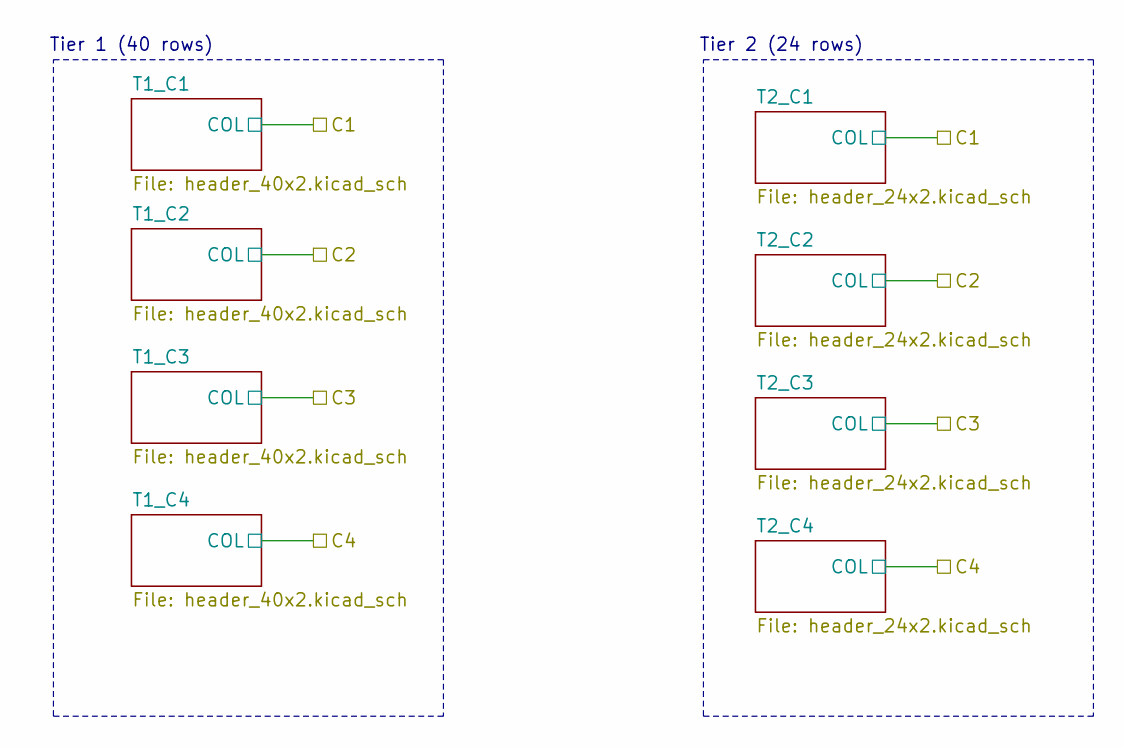
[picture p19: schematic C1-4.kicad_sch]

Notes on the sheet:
Tier 1 (40 rows)
Tier 2 (24 rows)

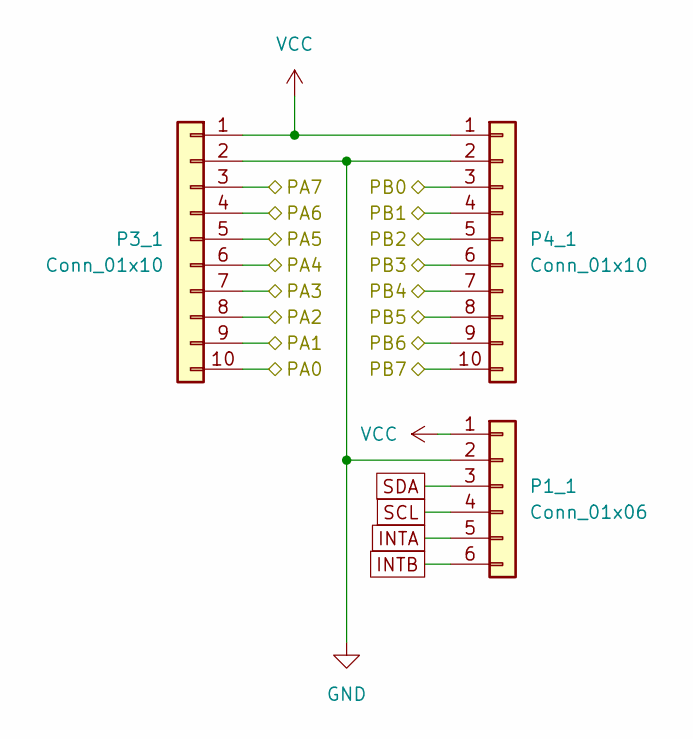
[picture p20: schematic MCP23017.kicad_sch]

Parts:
P1_1: Conn_01x06; PinSocket_1x06_P2.54mm_Vertical
P3_1, P4_1: Conn_01x10; PinSocket_1x10_P2.54mm_Vertical

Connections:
GND: P1_1.2, P3_1.2, P4_1.2; also elsewhere on the board
INTA: P1_1.5; also elsewhere on the board
INTB: P1_1.6; also elsewhere on the board
R1: P3_1.10; also elsewhere on the board
R2: P3_1.9; also elsewhere on the board
R3: P3_1.8; also elsewhere on the board
R4: P3_1.7; also elsewhere on the board
R5: P3_1.6; also elsewhere on the board
R6: P3_1.5; also elsewhere on the board
R7: P3_1.4; also elsewhere on the board
R8: P3_1.3; also elsewhere on the board
R9: P4_1.3; also elsewhere on the board
R10: P4_1.4; also elsewhere on the board
R11: P4_1.5; also elsewhere on the board
R12: P4_1.6; also elsewhere on the board
R13: P4_1.7; also elsewhere on the board
R14: P4_1.8; also elsewhere on the board
R15: P4_1.9; also elsewhere on the board
R16: P4_1.10; also elsewhere on the board
SCL: P1_1.4; also elsewhere on the board
SDA: P1_1.3; also elsewhere on the board
VCC: P1_1.1, P3_1.1, P4_1.1; also elsewhere on the board

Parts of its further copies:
P1_2, P1_3, P1_4: Conn_01x06; PinSocket_1x06_P2.54mm_Vertical
P3_2, P3_3, P3_4, P4_2, P4_3, P4_4: Conn_01x10; PinSocket_1x10_P2.54mm_Vertical

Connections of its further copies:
C1: P3_3.10; also elsewhere on the board
C2: P3_3.9; also elsewhere on the board
C3: P3_3.8; also elsewhere on the board
C4: P3_3.7; also elsewhere on the board
C5: P3_3.6; also elsewhere on the board
C6: P3_3.5; also elsewhere on the board
C7: P3_3.4; also elsewhere on the board
C8: P3_3.3; also elsewhere on the board
C9: P4_3.3; also elsewhere on the board
C10: P4_3.4; also elsewhere on the board
C11: P4_3.5; also elsewhere on the board
C12: P4_3.6; also elsewhere on the board
C13: P4_3.7; also elsewhere on the board
C14: P4_3.8; also elsewhere on the board
C15: P4_3.9; also elsewhere on the board
C16: P4_3.10; also elsewhere on the board
C17: P3_4.10; also elsewhere on the board
C18: P3_4.9; also elsewhere on the board
C19: P3_4.8; also elsewhere on the board
C20: P3_4.7; also elsewhere on the board
C21: P3_4.6; also elsewhere on the board
C22: P3_4.5; also elsewhere on the board
C23: P3_4.4; also elsewhere on the board
C24: P3_4.3; also elsewhere on the board
C25: P4_4.3; also elsewhere on the board
C26: P4_4.4; also elsewhere on the board
C27: P4_4.5; also elsewhere on the board
C28: P4_4.6; also elsewhere on the board
C29: P4_4.7; also elsewhere on the board
C30: P4_4.8; also elsewhere on the board
C31: P4_4.9; also elsewhere on the board
C32: P4_4.10; also elsewhere on the board
GND: P1_2.2, P1_3.2, P1_4.2, P3_2.2, P3_3.2, P3_4.2, P4_2.2, P4_3.2, P4_4.2; also elsewhere on the board
INTA: P1_2.5, P1_3.5, P1_4.5; also elsewhere on the board
INTB: P1_2.6, P1_3.6, P1_4.6; also elsewhere on the board
R17: P3_2.10; also elsewhere on the board
R18: P3_2.9; also elsewhere on the board
R19: P3_2.8; also elsewhere on the board
R20: P3_2.7; also elsewhere on the board
R21: P3_2.6; also elsewhere on the board
R22: P3_2.5; also elsewhere on the board
R23: P3_2.4; also elsewhere on the board
R24: P3_2.3; also elsewhere on the board
R25: P4_2.3; also elsewhere on the board
R26: P4_2.4; also elsewhere on the board
R27: P4_2.5; also elsewhere on the board
R28: P4_2.6; also elsewhere on the board
R29: P4_2.7; also elsewhere on the board
R30: P4_2.8; also elsewhere on the board
R31: P4_2.9; also elsewhere on the board
R32: P4_2.10; also elsewhere on the board
SCL: P1_2.4, P1_3.4, P1_4.4; also elsewhere on the board
SDA: P1_2.3, P1_3.3, P1_4.3; also elsewhere on the board
VCC: P1_2.1, P1_3.1, P1_4.1, P3_2.1, P3_3.1, P3_4.1, P4_2.1, P4_3.1, P4_4.1; also elsewhere on the board

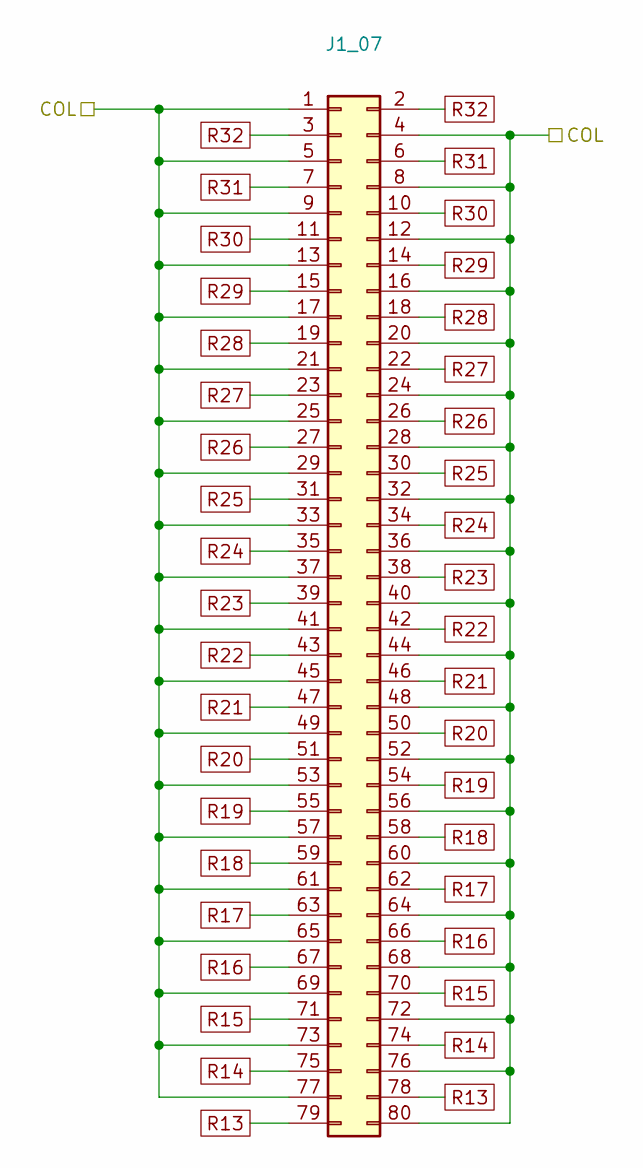
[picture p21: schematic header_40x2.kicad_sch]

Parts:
J1_07: Conn_02x40_Odd_Even; PinHeader_2x40_P2.54mm_Vertical

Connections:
C7: J1_07.1, J1_07.4, J1_07.5, J1_07.8, J1_07.9, J1_07.12, J1_07.13, J1_07.16, J1_07.17, J1_07.20, J1_07.21, J1_07.24, J1_07.25, J1_07.28, J1_07.29, J1_07.32, J1_07.33, J1_07.36, J1_07.37, J1_07.40, J1_07.41, J1_07.44, J1_07.45, J1_07.48, J1_07.49, J1_07.52, J1_07.53, J1_07.56, J1_07.57, J1_07.60, J1_07.61, J1_07.64, J1_07.65, J1_07.68, J1_07.69, J1_07.72, J1_07.73, J1_07.76, J1_07.77, J1_07.80; also elsewhere on the board
R13: J1_07.78, J1_07.79; also elsewhere on the board
R14: J1_07.74, J1_07.75; also elsewhere on the board
R15: J1_07.70, J1_07.71; also elsewhere on the board
R16: J1_07.66, J1_07.67; also elsewhere on the board
R17: J1_07.62, J1_07.63; also elsewhere on the board
R18: J1_07.58, J1_07.59; also elsewhere on the board
R19: J1_07.54, J1_07.55; also elsewhere on the board
R20: J1_07.50, J1_07.51; also elsewhere on the board
R21: J1_07.46, J1_07.47; also elsewhere on the board
R22: J1_07.42, J1_07.43; also elsewhere on the board
R23: J1_07.38, J1_07.39; also elsewhere on the board
R24: J1_07.34, J1_07.35; also elsewhere on the board
R25: J1_07.30, J1_07.31; also elsewhere on the board
R26: J1_07.26, J1_07.27; also elsewhere on the board
R27: J1_07.22, J1_07.23; also elsewhere on the board
R28: J1_07.18, J1_07.19; also elsewhere on the board
R29: J1_07.14, J1_07.15; also elsewhere on the board
R30: J1_07.10, J1_07.11; also elsewhere on the board
R31: J1_07.6, J1_07.7; also elsewhere on the board
R32: J1_07.2, J1_07.3; also elsewhere on the board

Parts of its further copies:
J1_01, J1_02, J1_03, J1_04, J1_05, J1_06, J1_08, J1_09, J1_10, J1_11, J1_12, J1_13, J1_14, J1_15, J1_16, J1_17, J1_18, J1_19, J1_20, J1_21, J1_22, J1_23, J1_24, J1_25, J1_26, J1_27, J1_28, J1_29, J1_30, J1_31, J1_32: Conn_02x40_Odd_Even; PinHeader_2x40_P2.54mm_Vertical

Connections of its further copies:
C1: J1_01.1, J1_01.4, J1_01.5, J1_01.8, J1_01.9, J1_01.12, J1_01.13, J1_01.16, J1_01.17, J1_01.20, J1_01.21, J1_01.24, J1_01.25, J1_01.28, J1_01.29, J1_01.32, J1_01.33, J1_01.36, J1_01.37, J1_01.40, J1_01.41, J1_01.44, J1_01.45, J1_01.48, J1_01.49, J1_01.52, J1_01.53, J1_01.56, J1_01.57, J1_01.60, J1_01.61, J1_01.64, J1_01.65, J1_01.68, J1_01.69, J1_01.72, J1_01.73, J1_01.76, J1_01.77, J1_01.80; also elsewhere on the board
C2: J1_02.1, J1_02.4, J1_02.5, J1_02.8, J1_02.9, J1_02.12, J1_02.13, J1_02.16, J1_02.17, J1_02.20, J1_02.21, J1_02.24, J1_02.25, J1_02.28, J1_02.29, J1_02.32, J1_02.33, J1_02.36, J1_02.37, J1_02.40, J1_02.41, J1_02.44, J1_02.45, J1_02.48, J1_02.49, J1_02.52, J1_02.53, J1_02.56, J1_02.57, J1_02.60, J1_02.61, J1_02.64, J1_02.65, J1_02.68, J1_02.69, J1_02.72, J1_02.73, J1_02.76, J1_02.77, J1_02.80; also elsewhere on the board
C3: J1_03.1, J1_03.4, J1_03.5, J1_03.8, J1_03.9, J1_03.12, J1_03.13, J1_03.16, J1_03.17, J1_03.20, J1_03.21, J1_03.24, J1_03.25, J1_03.28, J1_03.29, J1_03.32, J1_03.33, J1_03.36, J1_03.37, J1_03.40, J1_03.41, J1_03.44, J1_03.45, J1_03.48, J1_03.49, J1_03.52, J1_03.53, J1_03.56, J1_03.57, J1_03.60, J1_03.61, J1_03.64, J1_03.65, J1_03.68, J1_03.69, J1_03.72, J1_03.73, J1_03.76, J1_03.77, J1_03.80; also elsewhere on the board
C4: J1_04.1, J1_04.4, J1_04.5, J1_04.8, J1_04.9, J1_04.12, J1_04.13, J1_04.16, J1_04.17, J1_04.20, J1_04.21, J1_04.24, J1_04.25, J1_04.28, J1_04.29, J1_04.32, J1_04.33, J1_04.36, J1_04.37, J1_04.40, J1_04.41, J1_04.44, J1_04.45, J1_04.48, J1_04.49, J1_04.52, J1_04.53, J1_04.56, J1_04.57, J1_04.60, J1_04.61, J1_04.64, J1_04.65, J1_04.68, J1_04.69, J1_04.72, J1_04.73, J1_04.76, J1_04.77, J1_04.80; also elsewhere on the board
C5: J1_05.1, J1_05.4, J1_05.5, J1_05.8, J1_05.9, J1_05.12, J1_05.13, J1_05.16, J1_05.17, J1_05.20, J1_05.21, J1_05.24, J1_05.25, J1_05.28, J1_05.29, J1_05.32, J1_05.33, J1_05.36, J1_05.37, J1_05.40, J1_05.41, J1_05.44, J1_05.45, J1_05.48, J1_05.49, J1_05.52, J1_05.53, J1_05.56, J1_05.57, J1_05.60, J1_05.61, J1_05.64, J1_05.65, J1_05.68, J1_05.69, J1_05.72, J1_05.73, J1_05.76, J1_05.77, J1_05.80; also elsewhere on the board
C6: J1_06.1, J1_06.4, J1_06.5, J1_06.8, J1_06.9, J1_06.12, J1_06.13, J1_06.16, J1_06.17, J1_06.20, J1_06.21, J1_06.24, J1_06.25, J1_06.28, J1_06.29, J1_06.32, J1_06.33, J1_06.36, J1_06.37, J1_06.40, J1_06.41, J1_06.44, J1_06.45, J1_06.48, J1_06.49, J1_06.52, J1_06.53, J1_06.56, J1_06.57, J1_06.60, J1_06.61, J1_06.64, J1_06.65, J1_06.68, J1_06.69, J1_06.72, J1_06.73, J1_06.76, J1_06.77, J1_06.80; also elsewhere on the board
C8: J1_08.1, J1_08.4, J1_08.5, J1_08.8, J1_08.9, J1_08.12, J1_08.13, J1_08.16, J1_08.17, J1_08.20, J1_08.21, J1_08.24, J1_08.25, J1_08.28, J1_08.29, J1_08.32, J1_08.33, J1_08.36, J1_08.37, J1_08.40, J1_08.41, J1_08.44, J1_08.45, J1_08.48, J1_08.49, J1_08.52, J1_08.53, J1_08.56, J1_08.57, J1_08.60, J1_08.61, J1_08.64, J1_08.65, J1_08.68, J1_08.69, J1_08.72, J1_08.73, J1_08.76, J1_08.77, J1_08.80; also elsewhere on the board
C9: J1_09.1, J1_09.4, J1_09.5, J1_09.8, J1_09.9, J1_09.12, J1_09.13, J1_09.16, J1_09.17, J1_09.20, J1_09.21, J1_09.24, J1_09.25, J1_09.28, J1_09.29, J1_09.32, J1_09.33, J1_09.36, J1_09.37, J1_09.40, J1_09.41, J1_09.44, J1_09.45, J1_09.48, J1_09.49, J1_09.52, J1_09.53, J1_09.56, J1_09.57, J1_09.60, J1_09.61, J1_09.64, J1_09.65, J1_09.68, J1_09.69, J1_09.72, J1_09.73, J1_09.76, J1_09.77, J1_09.80; also elsewhere on the board
C10: J1_10.1, J1_10.4, J1_10.5, J1_10.8, J1_10.9, J1_10.12, J1_10.13, J1_10.16, J1_10.17, J1_10.20, J1_10.21, J1_10.24, J1_10.25, J1_10.28, J1_10.29, J1_10.32, J1_10.33, J1_10.36, J1_10.37, J1_10.40, J1_10.41, J1_10.44, J1_10.45, J1_10.48, J1_10.49, J1_10.52, J1_10.53, J1_10.56, J1_10.57, J1_10.60, J1_10.61, J1_10.64, J1_10.65, J1_10.68, J1_10.69, J1_10.72, J1_10.73, J1_10.76, J1_10.77, J1_10.80; also elsewhere on the board
C11: J1_11.1, J1_11.4, J1_11.5, J1_11.8, J1_11.9, J1_11.12, J1_11.13, J1_11.16, J1_11.17, J1_11.20, J1_11.21, J1_11.24, J1_11.25, J1_11.28, J1_11.29, J1_11.32, J1_11.33, J1_11.36, J1_11.37, J1_11.40, J1_11.41, J1_11.44, J1_11.45, J1_11.48, J1_11.49, J1_11.52, J1_11.53, J1_11.56, J1_11.57, J1_11.60, J1_11.61, J1_11.64, J1_11.65, J1_11.68, J1_11.69, J1_11.72, J1_11.73, J1_11.76, J1_11.77, J1_11.80; also elsewhere on the board
C12: J1_12.1, J1_12.4, J1_12.5, J1_12.8, J1_12.9, J1_12.12, J1_12.13, J1_12.16, J1_12.17, J1_12.20, J1_12.21, J1_12.24, J1_12.25, J1_12.28, J1_12.29, J1_12.32, J1_12.33, J1_12.36, J1_12.37, J1_12.40, J1_12.41, J1_12.44, J1_12.45, J1_12.48, J1_12.49, J1_12.52, J1_12.53, J1_12.56, J1_12.57, J1_12.60, J1_12.61, J1_12.64, J1_12.65, J1_12.68, J1_12.69, J1_12.72, J1_12.73, J1_12.76, J1_12.77, J1_12.80; also elsewhere on the board
C13: J1_13.1, J1_13.4, J1_13.5, J1_13.8, J1_13.9, J1_13.12, J1_13.13, J1_13.16, J1_13.17, J1_13.20, J1_13.21, J1_13.24, J1_13.25, J1_13.28, J1_13.29, J1_13.32, J1_13.33, J1_13.36, J1_13.37, J1_13.40, J1_13.41, J1_13.44, J1_13.45, J1_13.48, J1_13.49, J1_13.52, J1_13.53, J1_13.56, J1_13.57, J1_13.60, J1_13.61, J1_13.64, J1_13.65, J1_13.68, J1_13.69, J1_13.72, J1_13.73, J1_13.76, J1_13.77, J1_13.80; also elsewhere on the board
C14: J1_14.1, J1_14.4, J1_14.5, J1_14.8, J1_14.9, J1_14.12, J1_14.13, J1_14.16, J1_14.17, J1_14.20, J1_14.21, J1_14.24, J1_14.25, J1_14.28, J1_14.29, J1_14.32, J1_14.33, J1_14.36, J1_14.37, J1_14.40, J1_14.41, J1_14.44, J1_14.45, J1_14.48, J1_14.49, J1_14.52, J1_14.53, J1_14.56, J1_14.57, J1_14.60, J1_14.61, J1_14.64, J1_14.65, J1_14.68, J1_14.69, J1_14.72, J1_14.73, J1_14.76, J1_14.77, J1_14.80; also elsewhere on the board
C15: J1_15.1, J1_15.4, J1_15.5, J1_15.8, J1_15.9, J1_15.12, J1_15.13, J1_15.16, J1_15.17, J1_15.20, J1_15.21, J1_15.24, J1_15.25, J1_15.28, J1_15.29, J1_15.32, J1_15.33, J1_15.36, J1_15.37, J1_15.40, J1_15.41, J1_15.44, J1_15.45, J1_15.48, J1_15.49, J1_15.52, J1_15.53, J1_15.56, J1_15.57, J1_15.60, J1_15.61, J1_15.64, J1_15.65, J1_15.68, J1_15.69, J1_15.72, J1_15.73, J1_15.76, J1_15.77, J1_15.80; also elsewhere on the board
C16: J1_16.1, J1_16.4, J1_16.5, J1_16.8, J1_16.9, J1_16.12, J1_16.13, J1_16.16, J1_16.17, J1_16.20, J1_16.21, J1_16.24, J1_16.25, J1_16.28, J1_16.29, J1_16.32, J1_16.33, J1_16.36, J1_16.37, J1_16.40, J1_16.41, J1_16.44, J1_16.45, J1_16.48, J1_16.49, J1_16.52, J1_16.53, J1_16.56, J1_16.57, J1_16.60, J1_16.61, J1_16.64, J1_16.65, J1_16.68, J1_16.69, J1_16.72, J1_16.73, J1_16.76, J1_16.77, J1_16.80; also elsewhere on the board
C17: J1_17.1, J1_17.4, J1_17.5, J1_17.8, J1_17.9, J1_17.12, J1_17.13, J1_17.16, J1_17.17, J1_17.20, J1_17.21, J1_17.24, J1_17.25, J1_17.28, J1_17.29, J1_17.32, J1_17.33, J1_17.36, J1_17.37, J1_17.40, J1_17.41, J1_17.44, J1_17.45, J1_17.48, J1_17.49, J1_17.52, J1_17.53, J1_17.56, J1_17.57, J1_17.60, J1_17.61, J1_17.64, J1_17.65, J1_17.68, J1_17.69, J1_17.72, J1_17.73, J1_17.76, J1_17.77, J1_17.80; also elsewhere on the board
C18: J1_18.1, J1_18.4, J1_18.5, J1_18.8, J1_18.9, J1_18.12, J1_18.13, J1_18.16, J1_18.17, J1_18.20, J1_18.21, J1_18.24, J1_18.25, J1_18.28, J1_18.29, J1_18.32, J1_18.33, J1_18.36, J1_18.37, J1_18.40, J1_18.41, J1_18.44, J1_18.45, J1_18.48, J1_18.49, J1_18.52, J1_18.53, J1_18.56, J1_18.57, J1_18.60, J1_18.61, J1_18.64, J1_18.65, J1_18.68, J1_18.69, J1_18.72, J1_18.73, J1_18.76, J1_18.77, J1_18.80; also elsewhere on the board
C19: J1_19.1, J1_19.4, J1_19.5, J1_19.8, J1_19.9, J1_19.12, J1_19.13, J1_19.16, J1_19.17, J1_19.20, J1_19.21, J1_19.24, J1_19.25, J1_19.28, J1_19.29, J1_19.32, J1_19.33, J1_19.36, J1_19.37, J1_19.40, J1_19.41, J1_19.44, J1_19.45, J1_19.48, J1_19.49, J1_19.52, J1_19.53, J1_19.56, J1_19.57, J1_19.60, J1_19.61, J1_19.64, J1_19.65, J1_19.68, J1_19.69, J1_19.72, J1_19.73, J1_19.76, J1_19.77, J1_19.80; also elsewhere on the board
C20: J1_20.1, J1_20.4, J1_20.5, J1_20.8, J1_20.9, J1_20.12, J1_20.13, J1_20.16, J1_20.17, J1_20.20, J1_20.21, J1_20.24, J1_20.25, J1_20.28, J1_20.29, J1_20.32, J1_20.33, J1_20.36, J1_20.37, J1_20.40, J1_20.41, J1_20.44, J1_20.45, J1_20.48, J1_20.49, J1_20.52, J1_20.53, J1_20.56, J1_20.57, J1_20.60, J1_20.61, J1_20.64, J1_20.65, J1_20.68, J1_20.69, J1_20.72, J1_20.73, J1_20.76, J1_20.77, J1_20.80; also elsewhere on the board
C21: J1_21.1, J1_21.4, J1_21.5, J1_21.8, J1_21.9, J1_21.12, J1_21.13, J1_21.16, J1_21.17, J1_21.20, J1_21.21, J1_21.24, J1_21.25, J1_21.28, J1_21.29, J1_21.32, J1_21.33, J1_21.36, J1_21.37, J1_21.40, J1_21.41, J1_21.44, J1_21.45, J1_21.48, J1_21.49, J1_21.52, J1_21.53, J1_21.56, J1_21.57, J1_21.60, J1_21.61, J1_21.64, J1_21.65, J1_21.68, J1_21.69, J1_21.72, J1_21.73, J1_21.76, J1_21.77, J1_21.80; also elsewhere on the board
C22: J1_22.1, J1_22.4, J1_22.5, J1_22.8, J1_22.9, J1_22.12, J1_22.13, J1_22.16, J1_22.17, J1_22.20, J1_22.21, J1_22.24, J1_22.25, J1_22.28, J1_22.29, J1_22.32, J1_22.33, J1_22.36, J1_22.37, J1_22.40, J1_22.41, J1_22.44, J1_22.45, J1_22.48, J1_22.49, J1_22.52, J1_22.53, J1_22.56, J1_22.57, J1_22.60, J1_22.61, J1_22.64, J1_22.65, J1_22.68, J1_22.69, J1_22.72, J1_22.73, J1_22.76, J1_22.77, J1_22.80; also elsewhere on the board
C23: J1_23.1, J1_23.4, J1_23.5, J1_23.8, J1_23.9, J1_23.12, J1_23.13, J1_23.16, J1_23.17, J1_23.20, J1_23.21, J1_23.24, J1_23.25, J1_23.28, J1_23.29, J1_23.32, J1_23.33, J1_23.36, J1_23.37, J1_23.40, J1_23.41, J1_23.44, J1_23.45, J1_23.48, J1_23.49, J1_23.52, J1_23.53, J1_23.56, J1_23.57, J1_23.60, J1_23.61, J1_23.64, J1_23.65, J1_23.68, J1_23.69, J1_23.72, J1_23.73, J1_23.76, J1_23.77, J1_23.80; also elsewhere on the board
C24: J1_24.1, J1_24.4, J1_24.5, J1_24.8, J1_24.9, J1_24.12, J1_24.13, J1_24.16, J1_24.17, J1_24.20, J1_24.21, J1_24.24, J1_24.25, J1_24.28, J1_24.29, J1_24.32, J1_24.33, J1_24.36, J1_24.37, J1_24.40, J1_24.41, J1_24.44, J1_24.45, J1_24.48, J1_24.49, J1_24.52, J1_24.53, J1_24.56, J1_24.57, J1_24.60, J1_24.61, J1_24.64, J1_24.65, J1_24.68, J1_24.69, J1_24.72, J1_24.73, J1_24.76, J1_24.77, J1_24.80; also elsewhere on the board
C25: J1_25.1, J1_25.4, J1_25.5, J1_25.8, J1_25.9, J1_25.12, J1_25.13, J1_25.16, J1_25.17, J1_25.20, J1_25.21, J1_25.24, J1_25.25, J1_25.28, J1_25.29, J1_25.32, J1_25.33, J1_25.36, J1_25.37, J1_25.40, J1_25.41, J1_25.44, J1_25.45, J1_25.48, J1_25.49, J1_25.52, J1_25.53, J1_25.56, J1_25.57, J1_25.60, J1_25.61, J1_25.64, J1_25.65, J1_25.68, J1_25.69, J1_25.72, J1_25.73, J1_25.76, J1_25.77, J1_25.80; also elsewhere on the board
C26: J1_26.1, J1_26.4, J1_26.5, J1_26.8, J1_26.9, J1_26.12, J1_26.13, J1_26.16, J1_26.17, J1_26.20, J1_26.21, J1_26.24, J1_26.25, J1_26.28, J1_26.29, J1_26.32, J1_26.33, J1_26.36, J1_26.37, J1_26.40, J1_26.41, J1_26.44, J1_26.45, J1_26.48, J1_26.49, J1_26.52, J1_26.53, J1_26.56, J1_26.57, J1_26.60, J1_26.61, J1_26.64, J1_26.65, J1_26.68, J1_26.69, J1_26.72, J1_26.73, J1_26.76, J1_26.77, J1_26.80; also elsewhere on the board
C27: J1_27.1, J1_27.4, J1_27.5, J1_27.8, J1_27.9, J1_27.12, J1_27.13, J1_27.16, J1_27.17, J1_27.20, J1_27.21, J1_27.24, J1_27.25, J1_27.28, J1_27.29, J1_27.32, J1_27.33, J1_27.36, J1_27.37, J1_27.40, J1_27.41, J1_27.44, J1_27.45, J1_27.48, J1_27.49, J1_27.52, J1_27.53, J1_27.56, J1_27.57, J1_27.60, J1_27.61, J1_27.64, J1_27.65, J1_27.68, J1_27.69, J1_27.72, J1_27.73, J1_27.76, J1_27.77, J1_27.80; also elsewhere on the board
C28: J1_28.1, J1_28.4, J1_28.5, J1_28.8, J1_28.9, J1_28.12, J1_28.13, J1_28.16, J1_28.17, J1_28.20, J1_28.21, J1_28.24, J1_28.25, J1_28.28, J1_28.29, J1_28.32, J1_28.33, J1_28.36, J1_28.37, J1_28.40, J1_28.41, J1_28.44, J1_28.45, J1_28.48, J1_28.49, J1_28.52, J1_28.53, J1_28.56, J1_28.57, J1_28.60, J1_28.61, J1_28.64, J1_28.65, J1_28.68, J1_28.69, J1_28.72, J1_28.73, J1_28.76, J1_28.77, J1_28.80; also elsewhere on the board
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

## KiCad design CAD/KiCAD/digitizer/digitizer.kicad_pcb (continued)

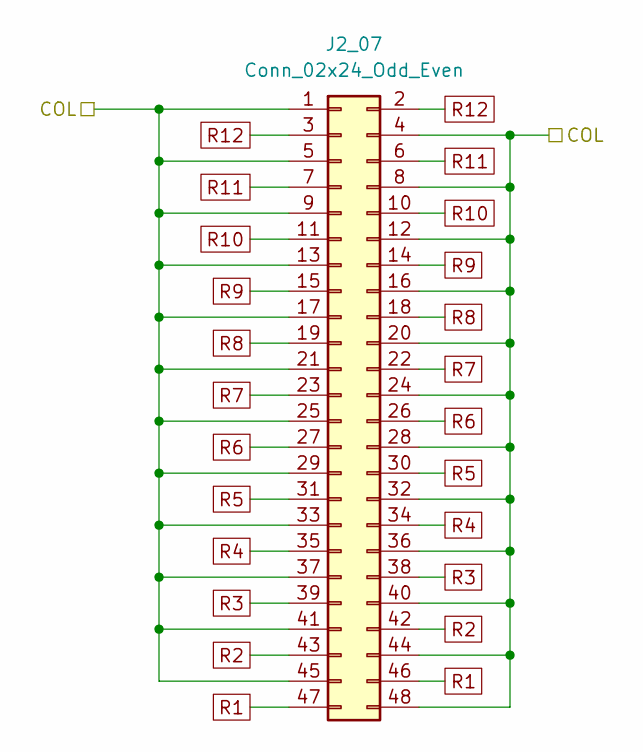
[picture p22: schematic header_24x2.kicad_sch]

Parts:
J2_07: Conn_02x24_Odd_Even; PinHeader_2x24_P2.54mm_Vertical

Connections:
C7: J2_07.1, J2_07.4, J2_07.5, J2_07.8, J2_07.9, J2_07.12, J2_07.13, J2_07.16, J2_07.17, J2_07.20, J2_07.21, J2_07.24, J2_07.25, J2_07.28, J2_07.29, J2_07.32, J2_07.33, J2_07.36, J2_07.37, J2_07.40, J2_07.41, J2_07.44, J2_07.45, J2_07.48; also elsewhere on the board
R1: J2_07.46, J2_07.47; also elsewhere on the board
R2: J2_07.42, J2_07.43; also elsewhere on the board
R3: J2_07.38, J2_07.39; also elsewhere on the board
R4: J2_07.34, J2_07.35; also elsewhere on the board
R5: J2_07.30, J2_07.31; also elsewhere on the board
R6: J2_07.26, J2_07.27; also elsewhere on the board
R7: J2_07.22, J2_07.23; also elsewhere on the board
R8: J2_07.18, J2_07.19; also elsewhere on the board
R9: J2_07.14, J2_07.15; also elsewhere on the board
R10: J2_07.10, J2_07.11; also elsewhere on the board
R11: J2_07.6, J2_07.7; also elsewhere on the board
R12: J2_07.2, J2_07.3; also elsewhere on the board

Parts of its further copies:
J2_01, J2_02, J2_03, J2_04, J2_05, J2_06, J2_08, J2_09, J2_10, J2_11, J2_12, J2_13, J2_14, J2_15, J2_16, J2_17, J2_18, J2_19, J2_20, J2_21, J2_22, J2_23, J2_24, J2_25, J2_26, J2_27, J2_28, J2_29, J2_30, J2_31, J2_32: Conn_02x24_Odd_Even; PinHeader_2x24_P2.54mm_Vertical

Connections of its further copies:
C1: J2_01.1, J2_01.4, J2_01.5, J2_01.8, J2_01.9, J2_01.12, J2_01.13, J2_01.16, J2_01.17, J2_01.20, J2_01.21, J2_01.24, J2_01.25, J2_01.28, J2_01.29, J2_01.32, J2_01.33, J2_01.36, J2_01.37, J2_01.40, J2_01.41, J2_01.44, J2_01.45, J2_01.48; also elsewhere on the board
C2: J2_02.1, J2_02.4, J2_02.5, J2_02.8, J2_02.9, J2_02.12, J2_02.13, J2_02.16, J2_02.17, J2_02.20, J2_02.21, J2_02.24, J2_02.25, J2_02.28, J2_02.29, J2_02.32, J2_02.33, J2_02.36, J2_02.37, J2_02.40, J2_02.41, J2_02.44, J2_02.45, J2_02.48; also elsewhere on the board
C3: J2_03.1, J2_03.4, J2_03.5, J2_03.8, J2_03.9, J2_03.12, J2_03.13, J2_03.16, J2_03.17, J2_03.20, J2_03.21, J2_03.24, J2_03.25, J2_03.28, J2_03.29, J2_03.32, J2_03.33, J2_03.36, J2_03.37, J2_03.40, J2_03.41, J2_03.44, J2_03.45, J2_03.48; also elsewhere on the board
C4: J2_04.1, J2_04.4, J2_04.5, J2_04.8, J2_04.9, J2_04.12, J2_04.13, J2_04.16, J2_04.17, J2_04.20, J2_04.21, J2_04.24, J2_04.25, J2_04.28, J2_04.29, J2_04.32, J2_04.33, J2_04.36, J2_04.37, J2_04.40, J2_04.41, J2_04.44, J2_04.45, J2_04.48; also elsewhere on the board
C5: J2_05.1, J2_05.4, J2_05.5, J2_05.8, J2_05.9, J2_05.12, J2_05.13, J2_05.16, J2_05.17, J2_05.20, J2_05.21, J2_05.24, J2_05.25, J2_05.28, J2_05.29, J2_05.32, J2_05.33, J2_05.36, J2_05.37, J2_05.40, J2_05.41, J2_05.44, J2_05.45, J2_05.48; also elsewhere on the board
C6: J2_06.1, J2_06.4, J2_06.5, J2_06.8, J2_06.9, J2_06.12, J2_06.13, J2_06.16, J2_06.17, J2_06.20, J2_06.21, J2_06.24, J2_06.25, J2_06.28, J2_06.29, J2_06.32, J2_06.33, J2_06.36, J2_06.37, J2_06.40, J2_06.41, J2_06.44, J2_06.45, J2_06.48; also elsewhere on the board
C8: J2_08.1, J2_08.4, J2_08.5, J2_08.8, J2_08.9, J2_08.12, J2_08.13, J2_08.16, J2_08.17, J2_08.20, J2_08.21, J2_08.24, J2_08.25, J2_08.28, J2_08.29, J2_08.32, J2_08.33, J2_08.36, J2_08.37, J2_08.40, J2_08.41, J2_08.44, J2_08.45, J2_08.48; also elsewhere on the board
C9: J2_09.1, J2_09.4, J2_09.5, J2_09.8, J2_09.9, J2_09.12, J2_09.13, J2_09.16, J2_09.17, J2_09.20, J2_09.21, J2_09.24, J2_09.25, J2_09.28, J2_09.29, J2_09.32, J2_09.33, J2_09.36, J2_09.37, J2_09.40, J2_09.41, J2_09.44, J2_09.45, J2_09.48; also elsewhere on the board
C10: J2_10.1, J2_10.4, J2_10.5, J2_10.8, J2_10.9, J2_10.12, J2_10.13, J2_10.16, J2_10.17, J2_10.20, J2_10.21, J2_10.24, J2_10.25, J2_10.28, J2_10.29, J2_10.32, J2_10.33, J2_10.36, J2_10.37, J2_10.40, J2_10.41, J2_10.44, J2_10.45, J2_10.48; also elsewhere on the board
C11: J2_11.1, J2_11.4, J2_11.5, J2_11.8, J2_11.9, J2_11.12, J2_11.13, J2_11.16, J2_11.17, J2_11.20, J2_11.21, J2_11.24, J2_11.25, J2_11.28, J2_11.29, J2_11.32, J2_11.33, J2_11.36, J2_11.37, J2_11.40, J2_11.41, J2_11.44, J2_11.45, J2_11.48; also elsewhere on the board
C12: J2_12.1, J2_12.4, J2_12.5, J2_12.8, J2_12.9, J2_12.12, J2_12.13, J2_12.16, J2_12.17, J2_12.20, J2_12.21, J2_12.24, J2_12.25, J2_12.28, J2_12.29, J2_12.32, J2_12.33, J2_12.36, J2_12.37, J2_12.40, J2_12.41, J2_12.44, J2_12.45, J2_12.48; also elsewhere on the board
C13: J2_13.1, J2_13.4, J2_13.5, J2_13.8, J2_13.9, J2_13.12, J2_13.13, J2_13.16, J2_13.17, J2_13.20, J2_13.21, J2_13.24, J2_13.25, J2_13.28, J2_13.29, J2_13.32, J2_13.33, J2_13.36, J2_13.37, J2_13.40, J2_13.41, J2_13.44, J2_13.45, J2_13.48; also elsewhere on the board
C14: J2_14.1, J2_14.4, J2_14.5, J2_14.8, J2_14.9, J2_14.12, J2_14.13, J2_14.16, J2_14.17, J2_14.20, J2_14.21, J2_14.24, J2_14.25, J2_14.28, J2_14.29, J2_14.32, J2_14.33, J2_14.36, J2_14.37, J2_14.40, J2_14.41, J2_14.44, J2_14.45, J2_14.48; also elsewhere on the board
C15: J2_15.1, J2_15.4, J2_15.5, J2_15.8, J2_15.9, J2_15.12, J2_15.13, J2_15.16, J2_15.17, J2_15.20, J2_15.21, J2_15.24, J2_15.25, J2_15.28, J2_15.29, J2_15.32, J2_15.33, J2_15.36, J2_15.37, J2_15.40, J2_15.41, J2_15.44, J2_15.45, J2_15.48; also elsewhere on the board
C16: J2_16.1, J2_16.4, J2_16.5, J2_16.8, J2_16.9, J2_16.12, J2_16.13, J2_16.16, J2_16.17, J2_16.20, J2_16.21, J2_16.24, J2_16.25, J2_16.28, J2_16.29, J2_16.32, J2_16.33, J2_16.36, J2_16.37, J2_16.40, J2_16.41, J2_16.44, J2_16.45, J2_16.48; also elsewhere on the board
C17: J2_17.1, J2_17.4, J2_17.5, J2_17.8, J2_17.9, J2_17.12, J2_17.13, J2_17.16, J2_17.17, J2_17.20, J2_17.21, J2_17.24, J2_17.25, J2_17.28, J2_17.29, J2_17.32, J2_17.33, J2_17.36, J2_17.37, J2_17.40, J2_17.41, J2_17.44, J2_17.45, J2_17.48; also elsewhere on the board
C18: J2_18.1, J2_18.4, J2_18.5, J2_18.8, J2_18.9, J2_18.12, J2_18.13, J2_18.16, J2_18.17, J2_18.20, J2_18.21, J2_18.24, J2_18.25, J2_18.28, J2_18.29, J2_18.32, J2_18.33, J2_18.36, J2_18.37, J2_18.40, J2_18.41, J2_18.44, J2_18.45, J2_18.48; also elsewhere on the board
C19: J2_19.1, J2_19.4, J2_19.5, J2_19.8, J2_19.9, J2_19.12, J2_19.13, J2_19.16, J2_19.17, J2_19.20, J2_19.21, J2_19.24, J2_19.25, J2_19.28, J2_19.29, J2_19.32, J2_19.33, J2_19.36, J2_19.37, J2_19.40, J2_19.41, J2_19.44, J2_19.45, J2_19.48; also elsewhere on the board
C20: J2_20.1, J2_20.4, J2_20.5, J2_20.8, J2_20.9, J2_20.12, J2_20.13, J2_20.16, J2_20.17, J2_20.20, J2_20.21, J2_20.24, J2_20.25, J2_20.28, J2_20.29, J2_20.32, J2_20.33, J2_20.36, J2_20.37, J2_20.40, J2_20.41, J2_20.44, J2_20.45, J2_20.48; also elsewhere on the board
C21: J2_21.1, J2_21.4, J2_21.5, J2_21.8, J2_21.9, J2_21.12, J2_21.13, J2_21.16, J2_21.17, J2_21.20, J2_21.21, J2_21.24, J2_21.25, J2_21.28, J2_21.29, J2_21.32, J2_21.33, J2_21.36, J2_21.37, J2_21.40, J2_21.41, J2_21.44, J2_21.45, J2_21.48; also elsewhere on the board
C22: J2_22.1, J2_22.4, J2_22.5, J2_22.8, J2_22.9, J2_22.12, J2_22.13, J2_22.16, J2_22.17, J2_22.20, J2_22.21, J2_22.24, J2_22.25, J2_22.28, J2_22.29, J2_22.32, J2_22.33, J2_22.36, J2_22.37, J2_22.40, J2_22.41, J2_22.44, J2_22.45, J2_22.48; also elsewhere on the board
C23: J2_23.1, J2_23.4, J2_23.5, J2_23.8, J2_23.9, J2_23.12, J2_23.13, J2_23.16, J2_23.17, J2_23.20, J2_23.21, J2_23.24, J2_23.25, J2_23.28, J2_23.29, J2_23.32, J2_23.33, J2_23.36, J2_23.37, J2_23.40, J2_23.41, J2_23.44, J2_23.45, J2_23.48; also elsewhere on the board
C24: J2_24.1, J2_24.4, J2_24.5, J2_24.8, J2_24.9, J2_24.12, J2_24.13, J2_24.16, J2_24.17, J2_24.20, J2_24.21, J2_24.24, J2_24.25, J2_24.28, J2_24.29, J2_24.32, J2_24.33, J2_24.36, J2_24.37, J2_24.40, J2_24.41, J2_24.44, J2_24.45, J2_24.48; also elsewhere on the board
C25: J2_25.1, J2_25.4, J2_25.5, J2_25.8, J2_25.9, J2_25.12, J2_25.13, J2_25.16, J2_25.17, J2_25.20, J2_25.21, J2_25.24, J2_25.25, J2_25.28, J2_25.29, J2_25.32, J2_25.33, J2_25.36, J2_25.37, J2_25.40, J2_25.41, J2_25.44, J2_25.45, J2_25.48; also elsewhere on the board
C26: J2_26.1, J2_26.4, J2_26.5, J2_26.8, J2_26.9, J2_26.12, J2_26.13, J2_26.16, J2_26.17, J2_26.20, J2_26.21, J2_26.24, J2_26.25, J2_26.28, J2_26.29, J2_26.32, J2_26.33, J2_26.36, J2_26.37, J2_26.40, J2_26.41, J2_26.44, J2_26.45, J2_26.48; also elsewhere on the board
C27: J2_27.1, J2_27.4, J2_27.5, J2_27.8, J2_27.9, J2_27.12, J2_27.13, J2_27.16, J2_27.17, J2_27.20, J2_27.21, J2_27.24, J2_27.25, J2_27.28, J2_27.29, J2_27.32, J2_27.33, J2_27.36, J2_27.37, J2_27.40, J2_27.41, J2_27.44, J2_27.45, J2_27.48; also elsewhere on the board
C28: J2_28.1, J2_28.4, J2_28.5, J2_28.8, J2_28.9, J2_28.12, J2_28.13, J2_28.16, J2_28.17, J2_28.20, J2_28.21, J2_28.24, J2_28.25, J2_28.28, J2_28.29, J2_28.32, J2_28.33, J2_28.36, J2_28.37, J2_28.40, J2_28.41, J2_28.44, J2_28.45, J2_28.48; also elsewhere on the board
C29: J2_29.1, J2_29.4, J2_29.5, J2_29.8, J2_29.9, J2_29.12, J2_29.13, J2_29.16, J2_29.17, J2_29.20, J2_29.21, J2_29.24, J2_29.25, J2_29.28, J2_29.29, J2_29.32, J2_29.33, J2_29.36, J2_29.37, J2_29.40, J2_29.41, J2_29.44, J2_29.45, J2_29.48; also elsewhere on the board
C30: J2_30.1, J2_30.4, J2_30.5, J2_30.8, J2_30.9, J2_30.12, J2_30.13, J2_30.16, J2_30.17, J2_30.20, J2_30.21, J2_30.24, J2_30.25, J2_30.28, J2_30.29, J2_30.32, J2_30.33, J2_30.36, J2_30.37, J2_30.40, J2_30.41, J2_30.44, J2_30.45, J2_30.48; also elsewhere on the board
C31: J2_31.1, J2_31.4, J2_31.5, J2_31.8, J2_31.9, J2_31.12, J2_31.13, J2_31.16, J2_31.17, J2_31.20, J2_31.21, J2_31.24, J2_31.25, J2_31.28, J2_31.29, J2_31.32, J2_31.33, J2_31.36, J2_31.37, J2_31.40, J2_31.41, J2_31.44, J2_31.45, J2_31.48; also elsewhere on the board
C32: J2_32.1, J2_32.4, J2_32.5, J2_32.8, J2_32.9, J2_32.12, J2_32.13, J2_32.16, J2_32.17, J2_32.20, J2_32.21, J2_32.24, J2_32.25, J2_32.28, J2_32.29, J2_32.32, J2_32.33, J2_32.36, J2_32.37, J2_32.40, J2_32.41, J2_32.44, J2_32.45, J2_32.48; also elsewhere on the board
R1: J2_01.46, J2_01.47, J2_02.46, J2_02.47, J2_03.46, J2_03.47, J2_04.46, J2_04.47, J2_05.46, J2_05.47, J2_06.46, J2_06.47, J2_08.46, J2_08.47, J2_09.46, J2_09.47, J2_10.46, J2_10.47, J2_11.46, J2_11.47, J2_12.46, J2_12.47, J2_13.46, J2_13.47, J2_14.46, J2_14.47, J2_15.46, J2_15.47, J2_16.46, J2_16.47, J2_17.46, J2_17.47, J2_18.46, J2_18.47, J2_19.46, J2_19.47, J2_20.46, J2_20.47, J2_21.46, J2_21.47, J2_22.46, J2_22.47, J2_23.46, J2_23.47, J2_24.46, J2_24.47, J2_25.46, J2_25.47, J2_26.46, J2_26.47, J2_27.46, J2_27.47, J2_28.46, J2_28.47, J2_29.46, J2_29.47, J2_30.46, J2_30.47, J2_31.46, J2_31.47, J2_32.46, J2_32.47; also elsewhere on the board
R2: J2_01.42, J2_01.43, J2_02.42, J2_02.43, J2_03.42, J2_03.43, J2_04.42, J2_04.43, J2_05.42, J2_05.43, J2_06.42, J2_06.43, J2_08.42, J2_08.43, J2_09.42, J2_09.43, J2_10.42, J2_10.43, J2_11.42, J2_11.43, J2_12.42, J2_12.43, J2_13.42, J2_13.43, J2_14.42, J2_14.43, J2_15.42, J2_15.43, J2_16.42, J2_16.43, J2_17.42, J2_17.43, J2_18.42, J2_18.43, J2_19.42, J2_19.43, J2_20.42, J2_20.43, J2_21.42, J2_21.43, J2_22.42, J2_22.43, J2_23.42, J2_23.43, J2_24.42, J2_24.43, J2_25.42, J2_25.43, J2_26.42, J2_26.43, J2_27.42, J2_27.43, J2_28.42, J2_28.43, J2_29.42, J2_29.43, J2_30.42, J2_30.43, J2_31.42, J2_31.43, J2_32.42, J2_32.43; also elsewhere on the board
R3: J2_01.38, J2_01.39, J2_02.38, J2_02.39, J2_03.38, J2_03.39, J2_04.38, J2_04.39, J2_05.38, J2_05.39, J2_06.38, J2_06.39, J2_08.38, J2_08.39, J2_09.38, J2_09.39, J2_10.38, J2_10.39, J2_11.38, J2_11.39, J2_12.38, J2_12.39, J2_13.38, J2_13.39, J2_14.38, J2_14.39, J2_15.38, J2_15.39, J2_16.38, J2_16.39, J2_17.38, J2_17.39, J2_18.38, J2_18.39, J2_19.38, J2_19.39, J2_20.38, J2_20.39, J2_21.38, J2_21.39, J2_22.38, J2_22.39, J2_23.38, J2_23.39, J2_24.38, J2_24.39, J2_25.38, J2_25.39, J2_26.38, J2_26.39, J2_27.38, J2_27.39, J2_28.38, J2_28.39, J2_29.38, J2_29.39, J2_30.38, J2_30.39, J2_31.38, J2_31.39, J2_32.38, J2_32.39; also elsewhere on the board
R4: J2_01.34, J2_01.35, J2_02.34, J2_02.35, J2_03.34, J2_03.35, J2_04.34, J2_04.35, J2_05.34, J2_05.35, J2_06.34, J2_06.35, J2_08.34, J2_08.35, J2_09.34, J2_09.35, J2_10.34, J2_10.35, J2_11.34, J2_11.35, J2_12.34, J2_12.35, J2_13.34, J2_13.35, J2_14.34, J2_14.35, J2_15.34, J2_15.35, J2_16.34, J2_16.35, J2_17.34, J2_17.35, J2_18.34, J2_18.35, J2_19.34, J2_19.35, J2_20.34, J2_20.35, J2_21.34, J2_21.35, J2_22.34, J2_22.35, J2_23.34, J2_23.35, J2_24.34, J2_24.35, J2_25.34, J2_25.35, J2_26.34, J2_26.35, J2_27.34, J2_27.35, J2_28.34, J2_28.35, J2_29.34, J2_29.35, J2_30.34, J2_30.35, J2_31.34, J2_31.35, J2_32.34, J2_32.35; also elsewhere on the board
R5: J2_01.30, J2_01.31, J2_02.30, J2_02.31, J2_03.30, J2_03.31, J2_04.30, J2_04.31, J2_05.30, J2_05.31, J2_06.30, J2_06.31, J2_08.30, J2_08.31, J2_09.30, J2_09.31, J2_10.30, J2_10.31, J2_11.30, J2_11.31, J2_12.30, J2_12.31, J2_13.30, J2_13.31, J2_14.30, J2_14.31, J2_15.30, J2_15.31, J2_16.30, J2_16.31, J2_17.30, J2_17.31, J2_18.30, J2_18.31, J2_19.30, J2_19.31, J2_20.30, J2_20.31, J2_21.30, J2_21.31, J2_22.30, J2_22.31, J2_23.30, J2_23.31, J2_24.30, J2_24.31, J2_25.30, J2_25.31, J2_26.30, J2_26.31, J2_27.30, J2_27.31, J2_28.30, J2_28.31, J2_29.30, J2_29.31, J2_30.30, J2_30.31, J2_31.30, J2_31.31, J2_32.30, J2_32.31; also elsewhere on the board
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

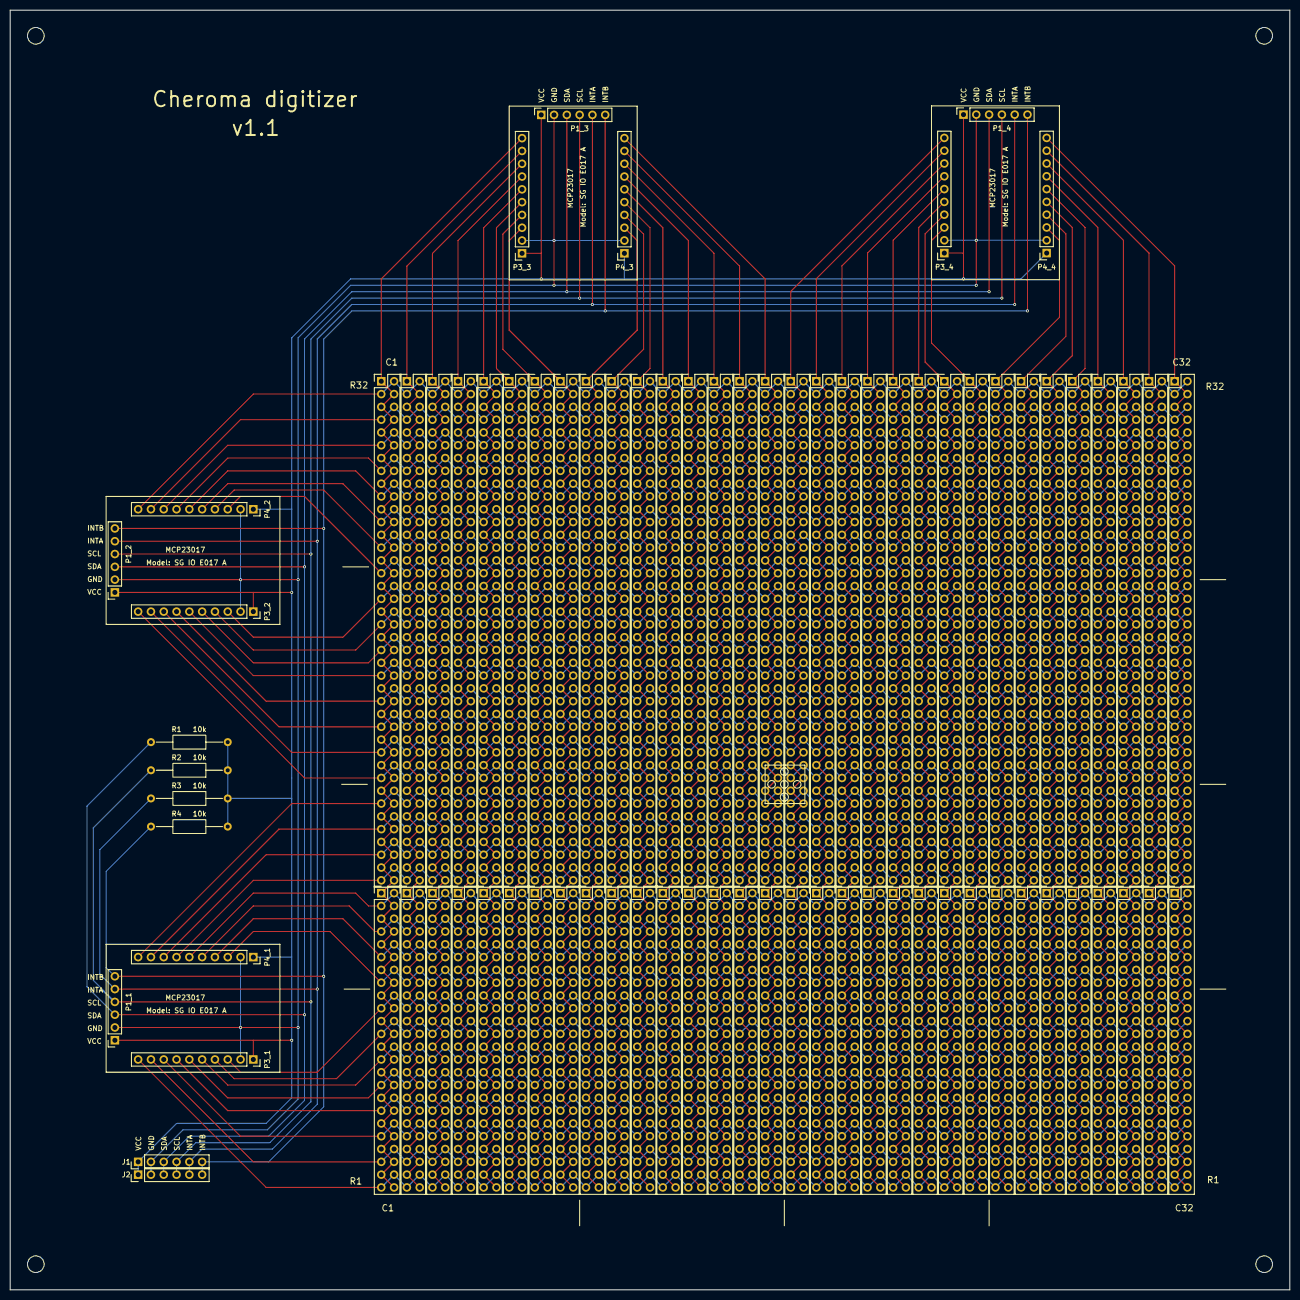
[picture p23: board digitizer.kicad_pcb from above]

Board: 2 copper layers, 254.0 x 254.0 mm, 82 parts (0 on the bottom side), 70 nets.

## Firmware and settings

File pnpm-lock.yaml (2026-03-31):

lockfileVersion: '9.0'

settings:
  autoInstallPeers: true
  excludeLinksFromLockfile: false

importers:

  .: {}

  apps/api:
    dependencies:
      '@savi2w/chess-tcn':
        specifier: ^1.0.0
        version: 1.0.0
      chess.js:
        specifier: ^1.4.0
        version: 1.4.0
      cors:
        specifier: ^2.8.5
        version: 2.8.5
      csv-parse:
        specifier: ^6.2.1
        version: 6.2.1
      esm-module-alias:
        specifier: ^2.2.1
        version: 2.2.1
      express:
        specifier: ^5.1.0
        version: 5.1.0
      http-errors-enhanced:
        specifier: ^3.0.2
        version: 3.0.2
      i2c-bus:
        specifier: ^5.2.3
        version: 5.2.3
      lodash-es:
        specifier: ^4.17.21
        version: 4.17.21
      mime:
        specifier: ^4.1.0
        version: 4.1.0
      ml-matrix:
        specifier: ^6.12.1
        version: 6.12.1
      morgan:
        specifier: ^1.10.1
        version: 1.10.1
      zod:
        specifier: ^4.1.12
        version: 4.1.12
    devDependencies:
      '@eslint/js':
        specifier: ^9.37.0
        version: 9.37.0
      '@types/express':
        specifier: ^5.0.3
        version: 5.0.3
      '@types/i2c-bus':
        specifier: ^5.1.2
        version: 5.1.2
      eslint:
        specifier: ^9.37.0
        version: 9.37.0
      eslint-import-resolver-alias:
        specifier: ^1.1.2
        version: 1.1.2(eslint-plugin-import@2.32.0(eslint@9.37.0))
      eslint-plugin-import:
        specifier: ^2.32.0
        version: 2.32.0(eslint@9.37.0)
      globals:
        specifier: ^16.4.0
        version: 16.4.0
      nodemon:
        specifier: ^3.1.10
        version: 3.1.10
    optionalDependencies:
      '@bratbit/onoff':
        specifier: ^1.0.7
        version: 1.0.7

packages:

  '@bratbit/onoff@1.0.7':
    resolution: {integrity: sha512-AmMG1p8DrX/7/jZiNPx8LewPA/ZDeQ3N4shuGjM8dC/Sx3ucif5Gv0JVJLaJR+oK5ERbwRIfjXR+RNXWa3z2lA==}

  '@eslint-community/eslint-utils@4.9.0':
    resolution: {integrity: sha512-ayVFHdtZ+hsq1t2Dy24wCmGXGe4q9Gu3smhLYALJrr473ZH27MsnSL+LKUlimp4BWJqMDMLmPpx/Q9R3OAlL4g==}
    engines: {node: ^12.22.0 || ^14.17.0 || >=16.0.0}
    peerDependencies:
      eslint: ^6.0.0 || ^7.0.0 || >=8.0.0

  '@eslint-community/regexpp@4.12.1':
    resolution: {integrity: sha512-CCZCDJuduB9OUkFkY2IgppNZMi2lBQgD2qzwXkEia16cge2pijY/aXi96CJMquDMn3nJdlPV1A5KrJEXwfLNzQ==}
    engines: {node: ^12.0.0 || ^14.0.0 || >=16.0.0}

  '@eslint/config-array@0.21.0':
    resolution: {integrity: sha512-ENIdc4iLu0d93HeYirvKmrzshzofPw6VkZRKQGe9Nv46ZnWUzcF1xV01dcvEg/1wXUR61OmmlSfyeyO7EvjLxQ==}
    engines: {node: ^18.18.0 || ^20.9.0 || >=21.1.0}

  '@eslint/config-helpers@0.4.0':
    resolution: {integrity: sha512-WUFvV4WoIwW8Bv0KeKCIIEgdSiFOsulyN0xrMu+7z43q/hkOLXjvb5u7UC9jDxvRzcrbEmuZBX5yJZz1741jog==}
    engines: {node: ^18.18.0 || ^20.9.0 || >=21.1.0}

  '@eslint/core@0.16.0':
    resolution: {integrity: sha512-nmC8/totwobIiFcGkDza3GIKfAw1+hLiYVrh3I1nIomQ8PEr5cxg34jnkmGawul/ep52wGRAcyeDCNtWKSOj4Q==}
    engines: {node: ^18.18.0 || ^20.9.0 || >=21.1.0}

  '@eslint/eslintrc@3.3.1':
    resolution: {integrity: sha512-gtF186CXhIl1p4pJNGZw8Yc6RlshoePRvE0X91oPGb3vZ8pM3qOS9W9NGPat9LziaBV7XrJWGylNQXkGcnM3IQ==}
    engines: {node: ^18.18.0 || ^20.9.0 || >=21.1.0}

  '@eslint/js@9.37.0':
    resolution: {integrity: sha512-jaS+NJ+hximswBG6pjNX0uEJZkrT0zwpVi3BA3vX22aFGjJjmgSTSmPpZCRKmoBL5VY/M6p0xsSJx7rk7sy5gg==}
    engines: {node: ^18.18.0 || ^20.9.0 || >=21.1.0}

  '@eslint/object-schema@2.1.6':
    resolution: {integrity: sha512-RBMg5FRL0I0gs51M/guSAj5/e14VQ4tpZnQNWwuDT66P14I43ItmPfIZRhO9fUVIPOAQXU47atlywZ/czoqFPA==}
    engines: {node: ^18.18.0 || ^20.9.0 || >=21.1.0}

  '@eslint/plugin-kit@0.4.0':
    resolution: {integrity: sha512-sB5uyeq+dwCWyPi31B2gQlVlo+j5brPlWx4yZBrEaRo/nhdDE8Xke1gsGgtiBdaBTxuTkceLVuVt/pclrasb0A==}
    engines: {node: ^18.18.0 || ^20.9.0 || >=21.1.0}

  '@humanfs/core@0.19.1':
    resolution: {integrity: sha512-5DyQ4+1JEUzejeK1JGICcideyfUbGixgS9jNgex5nqkW+cY7WZhxBigmieN5Qnw9ZosSNVC9KQKyb+GUaGyKUA==}
    engines: {node: '>=18.18.0'}

  '@humanfs/node@0.16.7':
    resolution: {integrity: sha512-/zUx+yOsIrG4Y43Eh2peDeKCxlRt/gET6aHfaKpuq267qXdYDFViVHfMaLyygZOnl0kGWxFIgsBy8QFuTLUXEQ==}
    engines: {node: '>=18.18.0'}

  '@humanwhocodes/module-importer@1.0.1':
    resolution: {integrity: sha512-bxveV4V8v5Yb4ncFTT3rPSgZBOpCkjfK0y4oVVVJwIuDVBRMDXrPyXRL988i5ap9m9bnyEEjWfm5WkBmtffLfA==}
    engines: {node: '>=12.22'}

  '@humanwhocodes/retry@0.4.3':
    resolution: {integrity: sha512-bV0Tgo9K4hfPCek+aMAn81RppFKv2ySDQeMoSZuvTASywNTnVJCArCZE2FWqpvIatKu7VMRLWlR1EazvVhDyhQ==}
    engines: {node: '>=18.18'}

  '@rtsao/scc@1.1.0':
    resolution: {integrity: sha512-zt6OdqaDoOnJ1ZYsCYGt9YmWzDXl4vQdKTyJev62gFhRGKdx7mcT54V9KIjg+d2wi9EXsPvAPKe7i7WjfVWB8g==}

  '@savi2w/chess-tcn@1.0.0':
    resolution: {integrity: sha512-pxRNNiCQTWRNtHDSxOUDMNNbXEmgYd3EKgERHsfw0DxHAjuPt2Pav8xErZ548Gpf3vd+6V0+npWIuWsF9NILOQ==}
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

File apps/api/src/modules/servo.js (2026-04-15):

import { writeRegister } from './i2c.js'
import { sleep } from './utils.js'
import { IKK } from '@/modules/kinematics.js'
import * as PCA9685 from '@/modules/drivers/PCA9685.js'
import { performance } from 'node:perf_hooks'
import { subscribe } from '@/modules/config.js'

/**
 * Live snapshot from config + motion state. Populated by `applyConfigFromSnapshot` (subscribe + immediate).
 * @type {{
 *   servos: ServoData
 *   dtMs: number
 *   isDebug: boolean
 *   angleDegToPulseUs: (args: { angleDeg: number | null, servoName: ServoName }) => number
 *   currentPosition: ServoPosition
 * }}
 */
const runtime = {
  servos: /** @type {ServoData} */ (/** @type {unknown} */ (null)),
  dtMs: 0,
  isDebug: false,
  angleDegToPulseUs: /** @type {(args: { angleDeg: number | null, servoName: ServoName }) => number} */ (
    () => {
      throw new Error('servo runtime not initialized (config subscribe did not run)')
    }
  ),
  currentPosition: /** @type {ServoPosition} */ (/** @type {unknown} */ (null))
}

/**
 * @param {'home' | 'init'} poseName
 * @returns {ServoPosition}
 */
const getPosePosition = (poseName) => {
  return Object.entries(runtime.servos).reduce(
    /** @param {*} acc */
    (acc, [servoName, servo]) => ({
      ...acc,
      [servoName]: servo[poseName]
    }),
    {}
  )
}

/**
 * @param {ServoPosition} position
 */
const setCurrentPosition = (position) => {
  runtime.currentPosition = { ...position }
}

/**
 * @param {ServoData} servos
 * @param {{ clamp?: boolean }} [options]
 */
const buildAngleDegToPulseUs = (servos, { clamp = true } = {}) => {
  const interp = (angle, begin, end) => {
    const [a0, u0] = begin
    const [a1, u1] = end
    if (a1 === a0) throw new Error('Duplicate angleDeg in sortedPoints')
    const t = (angle - a0) / (a1 - a0)
    // IMPORTANT: keep as float microseconds here.
    // Rounding too early causes "stair-step" motion when angle increments are small.
    return u0 + t * (u1 - u0)
  }

  const angleDegToPulseUsRaw = (angleDeg, { sortedPoints, clamp: clampAngle = true }) => {
    if (!Array.isArray(sortedPoints) || sortedPoints.length < 2) {
      throw new Error('sortedPoints must have at least 2 [angleDeg, pulseUs] points')
    }
    const n = sortedPoints.length
    if (angleDeg <= sortedPoints[0][0]) {
      if (clampAngle) {
        return sortedPoints[0][1]
      }
      return interp(angleDeg, sortedPoints[0], sortedPoints[1])
    }
    if (angleDeg >= sortedPoints[n - 1][0]) {
      if (clampAngle) {
        return sortedPoints[n - 1][1]
      }
      return interp(angleDeg, sortedPoints[n - 2], sortedPoints[n - 1])
    }
    let lo = 0
    let hi = n - 1
    while (hi - lo > 1) {
      const mid = (lo + hi) >> 1
      if (sortedPoints[mid][0] <= angleDeg) {
        lo = mid
      }
      else hi = mid
    }
    return interp(angleDeg, sortedPoints[lo], sortedPoints[lo + 1])
  }

  const perServo = Object.entries(servos).reduce(
    (acc, [servoName, { calPoints }]) => {
      const sortedPoints = calPoints.slice().sort(
        (a, b) => a[0] - b[0]
      )
      acc[servoName] = { sortedPoints }
      return acc
    },
    /** @type {Record<string, { sortedPoints: Array<ServoCalPoint> }>} */({})
  )
  return ({ angleDeg, servoName }) =>
    angleDegToPulseUsRaw(angleDeg, { ...perServo[servoName], clamp })
}

subscribe((config) => {
  runtime.servos = config.servos
  runtime.dtMs = config.drivers.pca9685.dtMs
  runtime.isDebug = config.options.debug
  runtime.angleDegToPulseUs = buildAngleDegToPulseUs(runtime.servos, { clamp: false })
  runtime.currentPosition = runtime.currentPosition ?? getPosePosition('init')
}, { immediate: true })

/**
 * @param {ServoPosition} position
 * @returns {Array<{ channel: number, pulseWidthUs: number }>}
 */
const positionToSetChannelsData = (position) => Object.entries(position).map(
  /** @param {*} arg */
  ([servoName, angleDeg]) => ({
    channel: runtime.servos[servoName].channel,
    pulseWidthUs: runtime.angleDegToPulseUs({ angleDeg, servoName })
  })
)

/**
 * @param {SetChannel} channel
 */
const setChannel = async ({ channel, pulseWidthUs }) => {
  const offTicks = Math.max(
    0,
    Math.min(
      4095,
      Math.round(pulseWidthUs * PCA9685.getFreq() * 4096 / 1e6)
    )
  )
  if (offTicks === 0) {
    await writeRegister(PCA9685.REGS.BASE + 4 * channel, Buffer.from([0x00, 0x00, 0x00, 0x10]), PCA9685.getDeviceAddr())
    return
  }
  if (offTicks >= 4095) {
    await writeRegister(PCA9685.REGS.BASE + 4 * channel, Buffer.from([0x00, 0x10, 0x00, 0x00]), PCA9685.getDeviceAddr())
    return
  }
  const off = Buffer.alloc(2)
  off.writeUInt16LE(offTicks)
  await writeRegister(PCA9685.REGS.BASE + 4 * channel, Buffer.from([0x00, 0x00, ...off]), PCA9685.getDeviceAddr())
}

/**
 * @param {Array<SetChannel>} channels
 */
const setChannels = async (channels) => {
  const sortedChannels = channels.slice().sort(
    (a, b) => a.channel - b.channel
  )
  const N = sortedChannels.length
  if (sortedChannels[0].channel + N - 1 !== sortedChannels[N - 1].channel) {
    throw new Error('Channels must be consecutive')
  }
  const defaultValue = Buffer.from([0x00, 0x00, 0x00, 0x10])
  const off = Buffer.alloc(2)
  const writeData = sortedChannels.reduce(
    (acc, { pulseWidthUs }) => {
      let value = defaultValue
      if (pulseWidthUs) {
        const offTicks = Math.max(
          0,
          Math.min(
            4095,
            Math.round(pulseWidthUs * PCA9685.getFreq() * 4096 / 1e6)
          )
        )
        off.writeUInt16LE(offTicks)
        value = Buffer.from([0x00, 0x00, ...off])
      }
      return Buffer.from([...acc, ...value])
    },
    Buffer.from([])
  )
  await writeRegister(PCA9685.REGS.BASE + 4 * sortedChannels[0].channel, writeData, PCA9685.getDeviceAddr())
}

const doRelax = async () => {
  await Promise.all(
    Object.keys(runtime.servos).map(
      async (servoName) => {
        const { channel } = runtime.servos[servoName]
        await setChannel({ channel, pulseWidthUs: 0 })
      }
    )
  )
}
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

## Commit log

2025-12-24 api: add basic servo
2025-12-26 api: add cal for 5 servos
2026-01-05 add 3d models and calibration scripts
    [B1.scad, B2.scad, B3.scad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]
2026-01-18 homing and new calibration added
2026-01-21 add arm controller
2026-01-21 add /arm/home-then-to endpoint
2026-01-23 add support for `via` in arm/to endpoint
2026-01-27 update config to list all geom props
2026-02-08 adopted basic 4-DOF design (with magnet)
2026-02-12 new calPoints (from disassembled arm)
2026-02-13 with magnet control
2026-02-20 new 3d parts
    [pcb_holder.FCStd, pcb_holder.stl, tcp_adapter.FCStd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]
2026-02-22 refactor board/move
2026-02-23 fixes for servo/toPoint
2026-02-23 set PWM freq to 250Hz
2026-02-24 optimization to support 400kHz i2c bus speed
2026-02-24 Optimizations for higher PWM frequency (250Hz) and i2c bus speed (400kHz)
2026-02-26 new fitting
    [test.FCStd]
2026-03-02 full board fitting
2026-03-03 new calPoints for base servo
2026-03-04 reset config + rearrange CAD files
    [B1.scad, B2.scad, B3.scad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]
2026-03-04 add digitizer draft
    [C1-4.kicad_sch, digitizer.kicad_pcb, digitizer.kicad_sch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]
2026-03-05 add digitizer tracks
    [digitizer.kicad_pcb]
2026-03-05 add MCP23017 for rows (no routing)
    [MCP23017.kicad_sch, digitizer.kicad_sch, header_40x2.kicad_sch]
2026-03-06 one MCP23017 added and routed
    [MCP23017.kicad_sch, digitizer.kicad_pcb, digitizer.kicad_sch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]
2026-03-06 routing wip take 1
    [MCP23017.kicad_sch, digitizer.kicad_pcb, digitizer.kicad_sch]
2026-03-07 digitizer draft with MCP23017 routing
    Made-with: Cursor
    [MCP23017.kicad_sch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]
2026-03-08 remove gerber files
    [MCP23017.kicad_sch, base.FCStd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]
2026-03-10 latest CAD files, pre-release
    [base.FCStd, digitizer-holder.stl, digitizer.kicad_pcb]
2026-03-10 updated digitizer holder CAD
    [base.FCStd, digitizer-holder.step, digitizer-holder.stl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]
2026-03-10 cad: add pull-up resistors to interrupt lines
    [digitizer.kicad_pcb, digitizer.kicad_sch]
2026-03-12 fix for incorrect offset
    [digitizer.js]
2026-03-13 disable interrupts in the meantime
2026-03-13 rearrange CAD files
    [digitizer-holder.step, pcb_holder.FCStd, pcb_holder.stl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]
2026-03-13 digitizer integration draft take 1
    [digitizer.kicad_pcb]
2026-03-14 digitizer casing rev1.1
    [base_rev1.1.FCStd, digitizer-holder-rev1.1.stl]
2026-03-18 freeCAD: add digitizer spacer model
    [spacer.FCStd, spacer.stl]
2026-03-18 freecad: update base and spacer designs
    [base_rev1.1.FCStd, base_rev1.1.stl, spacer.FCStd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]
2026-03-19 basic worker setup to poll the game progress (no arm moves)
2026-03-21 refactor to split i2c module from utils
2026-03-21 tunning of interrupt handling
2026-03-23 calibration first test
2026-03-23 implement median filter for calibration
2026-03-23 add arm motion to live game
2026-03-25 cad models for chess pieces
    [base_rev1.1.FCStd, base_rev1.1.stl, pieces-bishop.stl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]
2026-03-28 add hollow pieces
    [pieces 2.FCStd, pieces-bishop.stl, pieces-king.stl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]
2026-03-28 remove files from the root
    [pieces 2.FCStd, pieces-solid.FCStd, pieces.FCStd]
2026-03-29 cad: digitizer rev1.2
    [base_rev1.2.FCStd, base_rev1.2.stl, pieces-rook.stl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]
2026-03-29 cad: update spacer and base digitizer
    [base_rev1.2.FCStd, base_rev1.2.stl, spacer_rev1.1.FCStd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]
2026-03-29 calibration: slow down descent and go to preTarget after every touch before going home
2026-03-29 calibration: force rounding to 2 positions
2026-03-29 calibration: apply automatically collected measurement data
2026-03-30 cad: update digitizer to increase manufacturing tolerance
    [base.FCStd, base_rev1.1.FCStd, base_rev1.1.stl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]
2026-04-02 CV: refactor cameras enumeration
2026-04-03 cv: board geometry detection without markers
2026-04-04 cv: board detection wip (aruco, debug)
2026-04-04 cv: persist and reuse calibration data
2026-04-07 refactor modules/servo.js
2026-04-07 refactor servo.js
2026-04-07 refactor board.js
2026-04-08 api: refactor to add `arm` module
2026-04-11 fixes to calibration flow
    [calibration.js]
2026-04-15 cad: update chess pieces (non-functional)
    [pieces.FCStd]
